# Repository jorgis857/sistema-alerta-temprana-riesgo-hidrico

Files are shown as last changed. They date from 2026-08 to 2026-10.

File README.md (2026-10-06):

# 💧 WREWS — Water Risk Early Warning System

**Internet de las Cosas — Challenge #1 — 2026-2**
Facultad de Ingeniería, Universidad de La Sabana




[]()

> **WREWS (Water Risk Early Warning System)** es un prototipo IoT de bajo costo que monitorea la disponibilidad de agua y genera alertas tempranas ante condiciones asociadas a un posible riesgo de desabastecimiento. El sistema combina el nivel actual, las condiciones ambientales favorables a la evaporación y la velocidad de descenso del nivel para generar un **índice de riesgo hídrico** y comunicar localmente los estados 🟢 NORMAL, 🟡 PRECAUCIÓN y 🔴 CRÍTICO.

---

## 🎯 El reto

El Challenge #1 plantea el desarrollo de una solución IoT orientada al monitoreo de la disponibilidad de agua y a la generación de alertas tempranas locales.

WREWS aborda el problema mediante tres dimensiones principales:

```text
DISPONIBILIDAD ACTUAL
Nivel del reservorio
        50 %
          │
          │
CONDICIONES AMBIENTALES
VPD + irradiancia estimada
        30 %
          │
          ▼
    RIESGO HÍDRICO
          ▲
          │
TENDENCIA DEL NIVEL
Tasa de descenso
        20 %
```

El procesamiento se realiza localmente en un **ESP32**, por lo que la generación de la alerta no depende de Wi-Fi, Internet, servicios en la nube ni otra infraestructura de comunicaciones.

📄 **Documentación técnica completa:** [`/wiki`](wiki/00-Home.md)

---

## ✅ Estado actual

WREWS fue desarrollado mediante dos etapas complementarias:

### 1. Simulación en Wokwi

Se desarrolló inicialmente una simulación para:

- validar la arquitectura;
- probar la adquisición de sensores;
- comprobar el bus I²C;
- desarrollar y probar *custom chips*;
- verificar los cálculos;
- reproducir diferentes escenarios;
- validar los estados NORMAL, PRECAUCIÓN y CRÍTICO;
- depurar el firmware antes de integrar el hardware.

### 2. Prototipo físico

Posteriormente se construyó un **prototipo físico funcional** que integra:

- ESP32;
- sensor ultrasónico OKY3261/HC-SR04;
- BME280;
- mini panel fotovoltaico;
- INA219;
- LCD 16×2 I²C;
- LEDs verde, amarillo y rojo;
- buzzer;
- maqueta con plataforma móvil para representar diferentes niveles de agua.

Las pruebas físicas permitieron verificar la cadena completa:

```text
SENSADO
   ↓
ADQUISICIÓN
   ↓
PROCESAMIENTO
   ↓
FUSIÓN DE INFORMACIÓN
   ↓
CLASIFICACIÓN
   ↓
ALERTA LOCAL
```

---

## 🧭 Navegación rápida de la Wiki

| # | Sección | Contenido |
|---|---|---|
| 0 | [Home](wiki/00-Home.md) | Índice general de la Wiki |
| 1 | [Resumen, motivación y justificación](wiki/01-Resumen-Motivacion.md) | Contexto, problemática, objetivo y justificación |
| 2 | [Solución propuesta](wiki/02-Solucion-Propuesta.md) | Arquitectura, variables, procesamiento y lógica de riesgo |
| 3 | [Desarrollo modular](wiki/03-Desarrollo-Modular.md) | Modelo matemático, UML, hardware y estrategia de implementación |
| 4 | [Modelo de negocio](wiki/04-Modelo-de-Negocio.md) | Business Model Canvas |
| 5 | [Configuración experimental y resultados](wiki/05-Configuracion-Experimental-Resultados.md) | Simulación, pruebas físicas y análisis de resultados |
| 6 | [Autoevaluación del protocolo de pruebas](wiki/06-Autoevaluacion-Pruebas.md) | Cobertura, fortalezas y limitaciones |
| 7 | [Conclusiones, retos y trabajo futuro](wiki/07-Conclusiones-Trabajo-Futuro.md) | Resultados finales, retos y oportunidades de mejora |
| 8 | [Uso de Inteligencia Artificial](wiki/08-Uso-de-IA.md) | Declaración de uso de IA |
| 9 | [Equipo de trabajo](wiki/09-Equipo-Roles.md) | Roles, contribuciones, acta y autoevaluación |
| 10 | [Executive Summary (English)](wiki/10-English-Executive-Summary.md) | Resumen ejecutivo en inglés |
| 11 | [Conectividad IoT](wiki/11-Conectividad-IoT.md) | Actividad de refuerzo #2.3: red de nodos con MQTT |
| 12 | [Mejoras respecto al Challenge #1](wiki/12-Mejoras-Challenge-1.md) | Retroalimentación del Challenge #1 y cómo se atendió |

---

## 🗂️ Estructura del repositorio

```text
sistema-alerta-temprana-riesgo-hidrico/
├── README.md
├── LICENSE
│
├── wiki/
│   ├── 00-Home.md
│   ├── 01-Resumen-Motivacion.md
│   ├── 02-Solucion-Propuesta.md
│   ├── 03-Desarrollo-Modular.md
│   ├── 04-Modelo-de-Negocio.md
│   ├── 05-Configuracion-Experimental-Resultados.md
│   ├── 06-Autoevaluacion-Pruebas.md
│   ├── 07-Conclusiones-Trabajo-Futuro.md
│   ├── 08-Uso-de-IA.md
│   ├── 09-Equipo-Roles.md
│   ├── 10-English-Executive-Summary.md
│   ├── 11-Conectividad-IoT.md
│   └── 12-Mejoras-Challenge-1.md
│
├── firmware/
│   ├── wrews/                  (abrir wrews.ino en Arduino IDE)
│   │   ├── wrews.ino
│   │   ├── tablero.h
│   │   └── secrets.example.h   (copiar como secrets.h)
│   └── libraries.txt
│
├── hardware/
│   ├── wokwi/
│   │   ├── diagram.json
│   │   ├── wokwi-project-link.txt
│   │   └── chips/
│   └── schematics/
│       └── diagrama_circuito_wokwi.png
│
└── video/
    └── GUION_VIDEO.md
```

---

## ⚙️ Simulación en Wokwi

La simulación utilizada durante el desarrollo está disponible en:

**https://wokwi.com/projects/472250559337371649**

Para probarla:

1. Abrir el proyecto en Wokwi.
2. Iniciar la simulación.
3. Modificar los controles asociados a temperatura, humedad, presión e irradiancia.
4. Modificar la distancia del sensor ultrasónico.
5. Observar las variables calculadas y los cambios de estado.

La simulación permite reproducir:

```text
🟢 NORMAL
     ↓
🟡 PRECAUCIÓN
     ↓
🔴 CRÍTICO
```

> **Nota:** la simulación original utiliza una pantalla OLED SSD1306 como interfaz virtual. Durante la implementación física esta fue sustituida por una **LCD 16×2 I²C**. El firmware y los archivos almacenados en `hardware/wokwi/` corresponden a esta etapa de simulación y se conservan como evidencia del proceso de desarrollo.

---

## 🧩 Componentes del prototipo físico

| Función | Sensor / Actuador | Interfaz |
|---|---|---|
| Temperatura, humedad y presión | BME280 | I²C |
| Estimación de irradiancia | Mini panel fotovoltaico + INA219 | I²C |
| Nivel | OKY3261 / HC-SR04 | GPIO TRIG/ECHO |
| Visualización local | LCD 16×2 I²C | I²C |
| Alerta visual | LED verde / amarillo / rojo | GPIO digital |
| Alerta sonora | Buzzer | GPIO digital |
| Procesamiento | ESP32 | — |

---

## 🧠 Procesamiento del riesgo

WREWS utiliza tres componentes principales.

### 💧 Disponibilidad de agua

El sensor ultrasónico mide la distancia hasta la superficie que representa el agua.

Esta distancia se convierte en un porcentaje de nivel mediante la calibración correspondiente a las dimensiones de la maqueta.

### 🌡️ Condiciones ambientales

El BME280 obtiene temperatura y humedad relativa para calcular el **Vapor Pressure Deficit (VPD)**.

La señal obtenida mediante el panel fotovoltaico y el INA219 permite realizar una estimación experimental de irradiancia.

Ambas variables se combinan para obtener un **índice de condiciones favorables a la evaporación**.

### 📉 Tendencia

WREWS analiza diferentes mediciones del nivel a lo largo del tiempo para estimar su **tasa de descenso**.

Esto permite detectar reducciones aceleradas incluso antes de que el nivel alcance una condición extremadamente baja.

---

## 🚦 Sistema de alertas

La información procesada se transforma en tres estados:

| Estado | Indicador | Interpretación |
|---|---|---|
| 🟢 **NORMAL** | LED verde | Condiciones dentro del rango esperado |
| 🟡 **PRECAUCIÓN** | LED amarillo | Existen condiciones que requieren atención |
| 🔴 **CRÍTICO** | LED rojo + buzzer | Se detectó una condición de riesgo elevado |

La **LCD 16×2 I²C** proporciona información local adicional sobre el sistema.

---

## 🧪 Validación

La validación se realizó en dos niveles:

```text
WOKWI
Simulación controlada
      ↓
PROTOTIPO FÍSICO
Sensores + ESP32 + actuadores
      ↓
VALIDACIÓN FUNCIONAL
```

En el prototipo físico se verificó:

- respuesta del sensor ultrasónico;
- adquisición del BME280;
- adquisición del INA219 y panel;
- cálculo y procesamiento local;
- tasa de descenso;
- estados NORMAL, PRECAUCIÓN y CRÍTICO;
- LCD;
- LEDs;
- buzzer.

Para representar el nivel del agua se utilizó una **plataforma móvil** cuya altura puede modificarse frente al sensor ultrasónico.

Esto permite realizar pruebas repetibles sin exponer la electrónica directamente al agua.

Los resultados y el análisis completo se encuentran en:

[`wiki/05-Configuracion-Experimental-Resultados.md`](wiki/05-Configuracion-Experimental-Resultados.md)

---

## 🎥 Video de demostración

El video final presenta:

- problemática abordada;
- funcionamiento de WREWS;
- sensores utilizados;
- procesamiento de las variables;
- VPD e índice evaporativo;
- tasa de descenso;
- clasificación del riesgo;
- demostración del prototipo físico;
- estados NORMAL, PRECAUCIÓN y CRÍTICO.

El guion utilizado durante la producción se encuentra en:

[`video/GUION_VIDEO.md`](video/GUION_VIDEO.md)

> 🎬 **Video final de demostración:** [WREWS — Water Risk Early Warning System](https://youtu.be/zUS3DWeHSsw)

---

## 👥 Equipo 2

| Integrante | Rol principal |
|---|---|
| **Mateo Ramírez Cabrera** | Hardware e integración de sensores |
| **Antonio Benítez Rueda** | Firmware y lógica de fusión de datos |
| **Jorge Andrés Rodríguez Huertas** | Documentación, pruebas y gestión del proyecto |

El detalle de las contribuciones, compromisos y autoevaluación se encuentra en:

[`wiki/09-Equipo-Roles.md`](wiki/09-Equipo-Roles.md)

---

## 🤖 Uso de Inteligencia Artificial

El proyecto utilizó herramientas de Inteligencia Artificial como apoyo durante diferentes etapas del desarrollo.

La declaración y descripción correspondiente se mantiene documentada en:

[`wiki/08-Uso-de-IA.md`](wiki/08-Uso-de-IA.md)

---

## 📌 Resultado

WREWS evolucionó desde una arquitectura simulada hasta un **prototipo físico funcional**.

El sistema integra:

```text
NIVEL
   +
CONDICIONES AMBIENTALES
   +
TASA DE DESCENSO
   ↓
ÍNDICE DE RIESGO HÍDRICO
   ↓
NORMAL / PRECAUCIÓN / CRÍTICO
   ↓
LCD + LEDs + Buzzer
```

El prototipo demuestra la posibilidad de generar una **alerta temprana local de riesgo hídrico** mediante sensores de bajo costo y procesamiento embebido en un ESP32.

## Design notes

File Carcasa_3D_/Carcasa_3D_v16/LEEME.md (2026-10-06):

# WREWS – Carcasa v16 (el USB-C ya no choca con la cápsula del BME)

La caja mide **136 × 110 × 73 mm**. Reemplaza la v15. Son las 6 piezas completas, listas para imprimir.

## Qué cambió respecto a la v15

El problema real no era el agujerito de los cables del BME: era **el hueco del USB-C con su capucha**, que al ensanchar la caja en la v14 quedó justo encima de la cápsula del BME (la capucha del USB ocupaba X 1–25 mm y la cápsula X −15 a 15 mm, a la misma altura). Por eso en los intentos anteriores seguía viéndose igual.

- El hueco del USB-C se movió a **X = 42 mm** (hacia el lado de la proto, lejos del centro). Ahora queda **15 mm separado de la cápsula del BME** y 3 mm antes del tornillo de la esquina. Sigue estando dentro del ancho de la mini proto.
- Se devolvieron las **5 persianas** de la cápsula y el agujero de cables del BME a su posición original (nunca fueron el problema).
- Las 6 piezas se regeneraron y todas dan watertight = True.

**Importante al armar:** pongan el ESP32 en la mini proto de forma que su puerto USB-C quede mirando a la pared de atrás y corrido hacia el lado de afuera (a unos 9 mm del centro de la proto, hacia la pared lateral). Si al armar queda en otro lado, me dicen la medida y lo ajusto, o se usa un cable USB-C un poco más largo por dentro.

## Por qué la caja quedó más ancha que en versiones anteriores (heredado de la v14)

El portapilas real mide **61,5 × 52,6 × 15 mm** — mucho más grande en huella (y más plano) que lo que se había asumido antes (31 × 58 × 30 mm). Con el ancho anterior (104 mm interior) el portapilas real y la mini proto (85 × 56 mm) no cabían lado a lado sin chocar. Por eso el ancho interior pasó de 104 a 130 mm.

Además, a todo se le dejó margen de sobra, no medidas justas:

| Elemento | Medida real | Medida usada en el modelo | Margen |
|---|---|---|---|
| Mini proto (ESP32+INA219) | 85 × 56 mm | 89 × 59 mm | +3–4 mm |
| Portapilas 4×AA | 61,5 × 52,6 mm | 64,5 × 55,6 mm (lado corto hacia el ancho de la caja) | +3 mm |
| Interruptor (balancín 3 pines, foto) | ~19×13 mm el cuerpo | hueco 22×16 mm, marco 29×23 mm, capucha con 9 mm de fondo | holgado a propósito |
| Ventana LCD | pantalla 71,1×24,3 mm | 76,1×29,3 mm | +5 mm |
| Ranura USB-C | conector real | 16×10 mm | +1,5 mm más que en v13 |
| Bolsillo del panel solar | grosor real + 3 mm | grosor real + 4 mm | +1 mm más |

Entre la bandeja de la proto y la del portapilas quedan 11 mm de separación, y 2,2 mm de margen a cada pared lateral (más el borde estructural de 1,2 mm).

## Piezas (en `stl/`)

| # | Archivo | Tiempo aprox. | Cómo imprimir |
|---|---|---|---|
| 1 | `1_prueba_ajuste_tubo.stl` | 40 min | Plano. Es opcional |
| 2 | `2_acople_tubo.stl` | 2–3 h | Brida sobre la cama |
| 3 | `3_tapa.stl` | 2–3 h | Techo hacia arriba, con soportes solo desde la cama (debajo del labio) |
| 4 | `4_caja.stl` | 8–10 h | Piso sobre la cama, sin soportes |
| 5 | `5_piso_intermedio.stl` | 1 h | Plano sobre la cama, sin soportes |
| 6 | `6_techo_bme.stl` | 15 min | El tapón hueco va sobre la cama; el techito queda arriba |

Material PETG o ASA, capa de 0,2 mm, 3–4 perímetros y relleno de 30–40 %. La `4_caja` es la que más tarda — arráncenla primero.

## Lo que sigue pendiente (sin tocar, para más adelante)

- Posición real del USB-C (`USB_OFF_X`, estimado en -20).
- Grosor real del panel solar (`PANEL_ALTO`, estimado en 7 mm).
- El layout donde el ESP32 queda "metido en la del BME" — sigue anotado para reorganizar en otra versión, no era urgente para imprimir mañana.

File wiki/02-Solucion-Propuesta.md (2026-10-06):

[⬅ Volver al índice](00-Home.md)

# 2. Solución propuesta

## 2.1 Descripción general
**WREWS (Water Risk Early Warning System)** es un prototipo funcional de bajo costo diseñado para monitorear la disponibilidad de agua y generar alertas tempranas de riesgo hídrico.

El sistema utiliza un **ESP32** como unidad central de adquisición y procesamiento. A partir de diferentes sensores se analizan tres dimensiones principales:

1. **Disponibilidad actual de agua**, mediante el nivel.
2. **Condiciones ambientales favorables a la evaporación**, mediante temperatura, humedad e irradiancia estimada.
3. **Tendencia del nivel**, mediante su tasa de descenso.

Estas variables son procesadas y fusionadas localmente para clasificar la situación en tres estados:

- 🟢 **NORMAL**
- 🟡 **PRECAUCIÓN**
- 🔴 **CRÍTICO**

La notificación se realiza de forma completamente local mediante una **pantalla LCD 16×2 I²C**, LEDs de estado y un buzzer.

En el Challenge #2 se añade un **tablero de control web** alojado en un servidor embebido en el ESP32 y publicado en la WLAN de la zona. Desde un navegador (PC o celular conectado a esa WLAN, con usuario y contraseña) las autoridades ven el valor actual y el histórico reciente de las variables, reciben avisos de cada cambio de estado, silencian la alarma física y calibran el equipo.

---

## 2.2 Restricciones y decisiones de diseño

| Tipo | Restricción / necesidad | Decisión de diseño |
|---|---|---|
| **Técnica** | El sistema debe monitorear la disponibilidad de agua | Se utiliza un sensor ultrasónico OKY3261/HC-SR04 para medir la distancia hasta la superficie y convertirla en porcentaje de nivel |
| **Técnica** | Deben considerarse variables ambientales | Se utiliza un BME280 para adquirir temperatura, humedad relativa y presión atmosférica |
| **Técnica** | Se requiere considerar la radiación solar | Se utiliza un mini panel fotovoltaico junto con un INA219 para obtener una señal relacionada con la irradiancia recibida |
| **Técnica** | Se requiere notificación *in situ* con alarma física y visualización en tiempo real | Toda la actuación es local mediante LCD 16×2 I²C, LEDs verde/amarillo/rojo y buzzer, y no depende de la red |
| **Técnica (Ch. #2)** | Tablero de control en un servidor web embebido, conectado a la WLAN de la zona; no MQTT | Servidor HTTP en el ESP32 (librería `WebServer`), en modo estación (STA) sobre la WLAN; sin broker ni nube |
| **Técnica (Ch. #2)** | La medición debe ejecutarse en una ISR o en un hilo distinto al principal | La medición corre en una tarea de FreeRTOS en el núcleo 0; las alarmas en otra tarea del núcleo 1; el servidor y el LCD en `loop()`. Dos mutex protegen el estado compartido y el bus I²C |
| **Seguridad (Ch. #2)** | Acceso al tablero restringido a dispositivos autorizados y conectados a la WLAN de la zona | Doble condición: el cliente debe estar en la misma subred del equipo y tener una sesión iniciada con usuario y contraseña (cookie con token aleatorio de 128 bits, bloqueo tras 5 intentos fallidos) |
| **Operativa (Ch. #2)** | El equipo debe instalarse cerrado, como producto terminado | Carcasa impresa en 3D (PETG), sensor de nivel dentro de un tubo de PVC sanitario de 3", alimentación por pilas con interruptor, y calibración desde el tablero sin abrir la caja |
| **Robustez (Ch. #2)** | Pérdida y reconexión de la WLAN | La alarma física no depende de la red; el ESP32 se reconecta solo y admite hasta dos redes configuradas |
| **Regulatoria · eléctrica** | Seguridad eléctrica cerca del agua: RETIE [32] | Todo funciona en muy baja tensión (pilas, 5 V y 3.3 V) dentro de la carcasa; no hay 110 V cerca del agua |
| **Regulatoria · agua** | Infraestructura de acueducto: Resolución 0330 de 2017, RAS [33] | El equipo es complementario: mide sin contacto dentro de un tubo de PVC y no interviene la tubería ni la operación del acueducto |
| **Regulatoria · intemperie** | Grado de protección de la envolvente: IEC 60529 [34] | Carcasa cerrada con el BME280 bajo un techo ventilado; el grado IP no se ensayó y se declara como trabajo futuro |
| **Regulatoria · gestión del riesgo** | Ley 1523 de 2012 [35]: a quién se reporta | El tablero está pensado para la junta de acueducto y la unidad municipal de gestión del riesgo; el registro de eventos con su hora sirve de soporte para el reporte |
| **Regulatoria · datos** | Ley 1581 de 2012 [36] | El tablero no maneja datos personales; el acceso es restringido y cada inicio de sesión y cada clave incorrecta quedan registrados con la dirección del dispositivo |
| **Regulatoria · espectro** | Uso de radiofrecuencia [37] | Wi-Fi en la banda de 2.4 GHz, de uso libre en Colombia |
| **Temporal** | Entrega en dos semanas a partir del Challenge #1 | Se reutilizaron ESP32, sensores, LCD y la lógica de fusión; lo nuevo se construyó por etapas (modelo, hilos, Wi-Fi y tablero, calibración) probando cada una en el hardware |
| **Temporal · muestreo** | Fenómenos lentos, pero la tasa necesita muchas muestras | Medición cada 1 s (mediana de 5 ecos para el nivel); evaporación sobre una ventana móvil; historial del tablero con un punto cada 2 s durante 10 min |
| **Técnica** | Los sensores utilizan diferentes interfaces | BME280, INA219 y LCD utilizan el bus I²C; el sensor ultrasónico utiliza GPIO digital para TRIG y ECHO |
| **Técnica** | El sistema debe detectar cambios en el comportamiento del nivel | Se comparan mediciones sucesivas para estimar la tasa de descenso |
| **Técnica** | Una condición crítica no debe quedar oculta por un promedio | Además del índice ponderado se utilizan reglas de seguridad independientes |
| **Económica** | El prototipo debe ser de bajo costo | Se seleccionaron componentes comerciales, accesibles y reutilizables |
| **Operativa** | El usuario debe interpretar fácilmente el estado | Se utilizan tres estados y una codificación semafórica: verde, amarillo y rojo |
| **Operativa** | El sistema debe funcionar sin infraestructura externa | Todo el procesamiento se ejecuta localmente en el ESP32 |

---

## 2.3 Variables monitoreadas

WREWS adquiere o calcula las siguientes variables:

| Variable | Fuente | Uso |
|---|---|---|
| Distancia | Sensor ultrasónico | Medición base para determinar el nivel |
| Nivel (%) | Calculado | Representa la disponibilidad actual de agua |
| Temperatura | BME280 | Cálculo de condiciones ambientales |
| Humedad relativa | BME280 | Cálculo de condiciones ambientales |
| Presión atmosférica | BME280 | Variable ambiental de contexto |
| Señal del panel | Panel + INA219 | Estimación de irradiancia |
| Irradiancia estimada | Calculada | Evaluación de condiciones favorables a la evaporación |
| VPD | Calculado | Representa la demanda evaporativa de la atmósfera |
| Radiación neta y evaporación potencial (mm/día) | Calculadas (Priestley-Taylor + FAO-56) | Estimación física de la evaporación de agua libre a escala diaria |
| Índice evaporativo | Calculado | Resume las condiciones favorables a la evaporación |
| Tasa de descenso | Calculada | Representa la tendencia del nivel |
| Índice de riesgo | Calculado | Fusión de disponibilidad, ambiente y tendencia |
| Estado | Calculado | NORMAL, PRECAUCIÓN o CRÍTICO |

---

## 2.4 Arquitectura general

```mermaid
flowchart LR

    ULTRA[Sensor ultrasónico<br/>Nivel]
    BME[BME280<br/>Temperatura<br/>Humedad<br/>Presión]
    PANEL[Mini panel<br/>fotovoltaico]
    INA[INA219]

    MCU[ESP32<br/>Adquisición y procesamiento]

    LCD[LCD 16x2<br/>I2C]
    LEDV[LED verde]
    LEDA[LED amarillo]
    LEDR[LED rojo]
    BUZZ[Buzzer]

    PANEL --> INA

    ULTRA --> MCU
    BME --> MCU
    INA --> MCU

    MCU --> LCD
    MCU --> LEDV
    MCU --> LEDA
    MCU --> LEDR
    MCU --> BUZZ

    WLAN[WLAN de la zona<br/>hotspot en la demo]
    NAV[Navegador<br/>PC / celular autorizado]
    MCU <-->|Wi-Fi STA · HTTP| WLAN
    WLAN <--> NAV
```

El **ESP32** constituye el núcleo del sistema.

Los sensores proporcionan la información de entrada, el microcontrolador realiza los cálculos y finalmente controla los dispositivos de salida según el riesgo detectado.

En el Challenge #2 el mismo ESP32 sirve el tablero de control: se une como estación a la WLAN de la zona y responde a los navegadores autorizados dentro de ella. No hay broker, nube ni servidor externo.

### Diagrama de bloques del software (Challenge #2)

```mermaid
flowchart LR
    subgraph N0["Núcleo 0"]
        TM[tareaMedicion · 1 s<br/>sensores → modelo → estado<br/>historial y eventos]
    end
    subgraph N1["Núcleo 1"]
        TA[tareaAlarmas · 10 ms<br/>LEDs y buzzer]
        LP[loop<br/>servidor web · Wi-Fi · LCD]
    end
    EST[(Estado compartido<br/>mtx_estado)]
    I2C[(Bus I²C<br/>mtx_i2c)]
    NVS[(Flash NVS<br/>calibración)]

    TM --> EST
    TA --> EST
    LP --> EST
    TM --> I2C
    LP --> I2C
    LP --> NVS
```

---

## 2.5 Flujo de procesamiento

El funcionamiento general de WREWS sigue el siguiente flujo:

```mermaid
flowchart TD

    A[Inicio] --> B[Lectura de sensores]

    B --> C[Calcular porcentaje de nivel]
    B --> D[Obtener temperatura y humedad]
    B --> E[Obtener señal del panel]

    D --> F[Calcular VPD]
    E --> G[Estimar irradiancia]

    F --> H[Calcular índice evaporativo]
    G --> H

    C --> I[Actualizar historial del nivel]
    I --> J[Calcular tasa de descenso]

    C --> K[Calcular déficit de nivel]

    K --> L[Fusión de información]
    H --> L
    J --> L

    L --> M[Calcular índice de riesgo]

    M --> N{Clasificación}

    N -->|Crítico| O[LCD + LED rojo + Buzzer]
    N -->|Precaución| P[LCD + LED amarillo]
    N -->|Normal| Q[LCD + LED verde]

    O --> B
    P --> B
    Q --> B
```

---

## 2.6 Medición del nivel

El sensor ultrasónico se instala sobre el punto de almacenamiento y mide la distancia hasta la superficie.

La relación general es:

```text
Distancia pequeña
        ↓
Nivel alto

Distancia grande
        ↓
Nivel bajo
```

El porcentaje de nivel se obtiene mediante una calibración basada en las posiciones correspondientes a lleno y vacío.

De forma general:

```text
Nivel (%) =
100 × (Distancia_vacío - Distancia_medida)
      -------------------------------------
      (Distancia_vacío - Distancia_lleno)
```

El resultado se limita al rango:

```text
0 % ≤ Nivel ≤ 100 %
```

En la implementación física, los valores de calibración corresponden a las dimensiones reales de la maqueta.

Para las pruebas se utiliza una **plataforma móvil que representa la superficie del agua**. Al modificar su altura se pueden reproducir diferentes niveles de manera controlada.

---

## 2.7 Condiciones ambientales

### Temperatura, humedad y presión

El BME280 proporciona:

```text
Temperatura
Humedad relativa
Presión atmosférica
```

La temperatura y la humedad se utilizan para calcular el **VPD — Vapor Pressure Deficit**.

Conceptualmente:

```text
TEMPERATURA ──┐
              ├──→ VPD
HUMEDAD ──────┘
```

Un VPD mayor representa condiciones atmosféricas más favorables para la pérdida de agua por evaporación.

La presión atmosférica se conserva como una variable ambiental complementaria.

Debido a que su variación esperada en un punto fijo es relativamente pequeña, no participa directamente como disparador principal del riesgo.

---

## 2.8 Estimación de irradiancia

La radiación solar se representa mediante un mini panel fotovoltaico.

La cadena de adquisición es:

```text
RADIACIÓN
    ↓
PANEL FOTOVOLTAICO
    ↓
INA219
    ↓
SEÑAL ELÉCTRICA
    ↓
IRRADIANCIA ESTIMADA
```

Cuando aumenta la energía luminosa recibida por el panel, cambia su respuesta eléctrica.

El INA219 permite adquirir esta señal para que el ESP32 pueda utilizarla dentro del procesamiento.

La irradiancia obtenida debe interpretarse como una **estimación experimental**.

El panel fotovoltaico no sustituye un piranómetro calibrado, por lo que una medición metrológica precisa en W/m² requeriría una calibración frente a un instrumento de referencia.

---

## 2.9 Índice de condiciones favorables a la evaporación

En el Challenge #2, WREWS estima la **evaporación potencial diaria** con el modelo de **Priestley-Taylor**, usando las ecuaciones de **FAO-56** para la radiación neta y los parámetros psicrométricos, y la combina con el VPD.

Conceptualmente:

```text
PANEL → INA219 → IRRADIANCIA ──┐
                               ├──→ RADIACIÓN NETA ──┐
TEMPERATURA · HUMEDAD ─────────┘                     ├──→ EVAPORACIÓN (mm/día) ── 70 %──┐
TEMPERATURA · PRESIÓN ───────────→ Δ/(Δ+γ) ──────────┘                                  ├──→ ÍNDICE EVAPORATIVO
TEMPERATURA · HUMEDAD ───────────→ VPD de la ventana ────────────────────────── 30 % ───┘
```

El resultado representa qué tan favorables son las condiciones ambientales para la evaporación. El detalle del modelo, sus constantes y sus referencias están en la [Sección 3.2.3](03-Desarrollo-Modular.md).

Es importante señalar que:

> **El índice evaporativo no representa el porcentaje de agua que se ha evaporado.**

Representa un indicador relativo de las **condiciones ambientales que favorecen la evaporación**.

---

## 2.10 Tasa de descenso

Una medición instantánea del nivel no permite determinar cómo está evolucionando el almacenamiento.

Por esta razón, WREWS compara mediciones tomadas en diferentes momentos.

Conceptualmente:

```text
Nivel anterior - Nivel actual
-----------------------------
       Tiempo transcurrido
```

Esto permite estimar la **tasa de descenso del nivel**.

Por ejemplo:

```text
Reservorio A
Nivel = 50 %
Tasa ≈ 0
→ relativamente estable

Reservorio B
Nivel = 50 %
Tasa de descenso alta
→ disponibilidad disminuyendo rápidamente
```

De esta forma, la tendencia aporta información adicional a la disponibilidad instantánea.

---

## 2.11 Fusión de información

La lógica principal combina tres componentes:

```text
                 WREWS

       DISPONIBILIDAD ACTUAL
          Déficit de nivel
                54 %
                 │
                 │
CONDICIONES ─────┼───── TENDENCIA
AMBIENTALES      │      DEL NIVEL
Priestley-Taylor │      Tasa de
+ VPD            │      descenso
30 %             │      16 %
                 │
                 ▼
          ÍNDICE DE RIESGO
                 │
                 ▼
       NORMAL / PRECAUCIÓN /
              CRÍTICO
```

La ponderación utilizada es:

```text
Riesgo =
0.54 × Déficit de nivel
+
0.30 × Índice evaporativo
+
0.16 × Tendencia
```

La mayor ponderación corresponde al nivel porque la **disponibilidad actual de agua constituye la variable principal del problema**. En el Challenge #2 los pesos pasaron de 50/30/20 a 54/30/16: son el vector de pesos del método AHP de Saaty aplicado a la comparación por pares de las tres señales (ver [Sección 3.2.5](03-Desarrollo-Modular.md)).

Las condiciones ambientales permiten anticipar escenarios favorables a una mayor pérdida de agua y la tendencia permite identificar reducciones aceleradas.

---

## 2.12 Reglas de seguridad

El índice ponderado no constituye el único mecanismo de decisión.

WREWS incorpora reglas de seguridad para condiciones individuales extremas.

Esto evita una situación como:

```text
Nivel extremadamente bajo
+
Ambiente favorable
+
Tasa estable
```

en la que el promedio matemático pudiera reducir artificialmente la percepción del riesgo.

Por tanto:

```text
ÍNDICE PONDERADO
       +
REGLAS DE SEGURIDAD
       ↓
ESTADO FINAL
```

Excepción introducida en el Challenge #2: la **evaporación por sí sola lleva como máximo a PRECAUCIÓN**. La evaporación es un forzante, no la disponibilidad de agua: un mediodía seco y soleado con el embalse lleno no es una emergencia. Su severidad completa se sigue mostrando en el tablero y entra al riesgo combinado con su peso, de modo que con el nivel bajo el riesgo sí lleva a CRÍTICO.

---

## 2.13 Estados del sistema

### 🟢 NORMAL

Representa condiciones en las que la disponibilidad de agua y los demás indicadores no muestran un riesgo significativo.

Respuesta local:

```text
LCD → NORMAL
LED verde → activo
Buzzer → apagado
```

### 🟡 PRECAUCIÓN

Indica que una o varias variables han alcanzado condiciones que justifican atención.

Respuesta local:

```text
LCD → PRECAUCIÓN
LED amarillo → activo
Buzzer → pitido grave corto (1000 Hz, 150 ms cada 4 s)
```

### 🔴 CRÍTICO

Representa una situación de riesgo elevado o una condición individual considerada crítica.

Respuesta local:

```text
LCD → CRÍTICO
LED rojo → parpadea
Buzzer → alarma sonora (2000 Hz, 250 ms cada 1.2 s)
```

### ⚙️ FALLO

Condición del equipo, no nivel de riesgo: sin eco del sensor de nivel o sin BME280 en el bus I²C.

```text
LEDs → los tres parpadean a la vez
Buzzer → tono muy grave (600 Hz, 120 ms cada 3 s)
```

En todos los estados el buzzer puede **silenciarse durante 15 minutos desde el tablero de control**; los LEDs siguen mostrando el estado, y si este empeora el silencio se cancela solo.

---

## 2.14 Visualización local

La implementación física utiliza una **LCD 16×2 I²C**.

Debido al espacio disponible en la pantalla, la información se organiza para presentar las variables más relevantes y el estado del sistema sin interferir con el procesamiento interno.

En el firmware v7 la LCD rota cada 2.5 s entre siete páginas:

| Página | Línea 1 | Línea 2 |
|---|---|---|
| 1 | Nivel (%) o `SIN ECO` | Estado (y `MUTE` si el buzzer está silenciado) |
| 2 | Temperatura | Humedad relativa |
| 3 | Presión | VPD |
| 4 | Irradiancia (`NOCHE` si < 5 W/m²) | Índice evaporativo, o `calc NN%` mientras se llena la ventana |
| 5 | Severidad de cada variable y riesgo | Tasa de descenso |
| 6 | Evaporación potencial (mm/día) | Radiación neta y modo (DEMO/CAMPO) |
| 7 | Estado del Wi-Fi | **IP del tablero** (o `buscando red...`) |

Los LEDs permiten interpretar rápidamente la clasificación:

```text
🟢 Verde     → NORMAL
🟡 Amarillo  → PRECAUCIÓN
🔴 Rojo      → CRÍTICO
```

El buzzer añade una señal sonora cuando se identifica una condición crítica, con un tono distinto para precaución, crítico y fallo.

---

## 2.15 Alerta local independiente de la red

Una característica importante del diseño es que la generación de la alerta no depende de infraestructura externa. En el Challenge #2 el tablero web se suma como un segundo canal de notificación, pero la cadena de abajo sigue completa aunque la WLAN no esté disponible.

Todo ocurre dentro del dispositivo:

```text
SENSORES
   ↓
ESP32
   ↓
PROCESAMIENTO
   ↓
DECISIÓN
   ↓
LCD + LEDs + BUZZER
```

No se requiere:

- Wi-Fi;
- Bluetooth;
- LoRa;
- GSM;
- servicios en la nube;
- conexión a Internet.

Esto permite que el sistema continúe generando alertas locales incluso en un lugar sin conectividad.

---

## 2.16 Simulación e implementación física

El desarrollo se realizó en dos etapas.

### Simulación

Wokwi permitió:

- diseñar la arquitectura;
- probar sensores;
- desarrollar *custom chips*;
- comprobar el bus I²C;
- probar escenarios controlados;
- verificar la lógica de riesgo;
- depurar el firmware.

La simulación original utiliza algunos componentes virtuales diferentes a los finalmente disponibles para el montaje físico.

### Implementación física

Posteriormente se integraron los componentes reales y se ajustó el sistema a las características de la maqueta.

La pantalla utilizada en el prototipo físico final es una **LCD 16×2 I²C**, seleccionada por disponibilidad y porque permite cumplir el requisito de visualización local.

Por tanto, la simulación debe entenderse como una etapa de desarrollo y validación previa, mientras que la implementación física representa la versión final presentada en el Challenge.

### Producto terminado (Challenge #2)

En el Challenge #2 el prototipo deja la maqueta de laboratorio y se integra como un equipo listo para instalar:

- **Carcasa** impresa en 3D en PETG, diseñada en CadQuery, con el ESP32, el INA219, el LCD, los LEDs y el buzzer dentro, el BME280 bajo un techo con rejillas de ventilación y el panel solar en la parte superior.
- **Sensor de nivel** dentro de un tubo de PVC sanitario de 3" (40 a 50 cm, con entradas de agua en la parte inferior), que se instala en el punto de almacenamiento.
- **Alimentación** por un portapilas 4×AA con interruptor.
- **Tablero de control** en la WLAN de la zona, que permite calibrar el equipo con la carcasa cerrada.

El detalle está en las [Secciones 3.14 a 3.19](03-Desarrollo-Modular.md).

---

## 2.17 Locación y contexto físico (Challenge #2)

| Aspecto | Definición del equipo |
|---|---|
| **Punto crítico** | Lago del campus de la Universidad de La Sabana (Chía, Sabana Centro) como sitio de instalación y pruebas; como alternativa, el tanque de un acueducto veredal de Chía o Cajicá. El nodo se instala en la orilla, anclado a un poste o baranda, y mide dentro de un tubo de PVC que llega por debajo del nivel mínimo |
| **Ambiente** | Intemperie a ≈ 2560 m s. n. m.: lluvia, radiación UV alta, heladas en temporada seca y humedad alta en la noche |
| **Alimentación** | Pilas en el prototipo; en campo, red de 5 V con respaldo o panel solar con baterías. El servidor web obliga a tener el Wi-Fi siempre encendido |
| **Conectividad** | WLAN de la junta o la alcaldía, con el punto de acceso a ≤ 30 m y línea de vista; objetivo de señal ≥ −70 dBm en el punto de instalación |
| **Acceso y mantenimiento** | Montaje con tornillería antivandalismo; mantenimiento mensual (limpiar el sensor, revisar la alimentación); calibración desde el tablero, sin tocar el agua |
| **Rango de variables** | Nivel: 0–2 m en un tanque típico (en el prototipo, el recorrido del tubo); temperatura ≈ 0–25 °C; HR 40–95 %; presión ≈ 750 hPa; radiación hasta ≈ 1100–1200 W/m² al mediodía |
| **Seguridad del sitio** | Solo muy baja tensión dentro de la caja; nada de 110 V cerca del agua |

⟨completar: fotos del sitio, medidas y RSSI medido en el punto de instalación, si se hizo la visita⟩

---

[⬅ Anterior: Resumen y motivación](01-Resumen-Motivacion.md) · [⬆ Índice](00-Home.md) · [Siguiente: Desarrollo modular ➡](03-Desarrollo-Modular.md)

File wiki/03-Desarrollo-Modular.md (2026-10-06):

[⬅ Volver al índice](00-Home.md)

# 3. Desarrollo teórico modular

## 3.1 Criterios de diseño establecidos

| Criterio | Decisión de diseño | Justificación |
|---|---|---|
| **Independencia de red** | Toda la lógica de decisión corre en el ESP32; no hay llamadas a servicios externos. El tablero del Challenge #2 solo publica lo que el equipo ya decidió | La alarma *in situ* funciona aunque la WLAN no esté disponible |
| **Medición en hilo propio (Ch. #2)** | Tres hilos de FreeRTOS: medición (núcleo 0), alarmas (núcleo 1) y servidor/LCD (`loop()`, núcleo 1) | Cumple la restricción del enunciado y evita que un navegador lento o una caída de la red congelen la alarma física |
| **Acceso restringido (Ch. #2)** | Misma subred que el equipo + sesión con usuario y contraseña | Solo dispositivos autorizados y conectados a la WLAN de la zona ven los datos o actúan sobre la alarma |
| **Producto cerrado (Ch. #2)** | Calibración desde el tablero, guardada en la flash del ESP32 | La carcasa no se abre para ajustar el equipo en el sitio |
| **Trazabilidad de los parámetros (Ch. #2)** | Cada constante del modelo cita su fuente en el código y en la Sección 7.5; las que no tienen fuente se declaran como supuesto | Responde a la observación del Challenge #1 de que los valores no se anclaban a literatura ni normativa |
| **Modularidad funcional** | El firmware se organiza por responsabilidades: lectura de sensores, cálculo de nivel, VPD, índice evaporativo, tasa de descenso, riesgo y actuación | Facilita mantenimiento, depuración y reemplazo de sensores |
| **Múltiples señales, una decisión** | El riesgo hídrico depende de la fusión de nivel, condiciones evaporativas y tendencia | Responde a la necesidad de combinar múltiples señales para una alerta más completa |
| **Ninguna variable crítica queda oculta por el promedio** | Se incorporan reglas de seguridad independientes al promedio ponderado | Reduce el riesgo de falsos negativos ante condiciones individuales extremas |
| **Calibración simple** | El nivel se ajusta mediante parámetros de distancia correspondientes a lleno y vacío (en el Challenge #2, desde el tablero) | Permite adaptar el sistema a distintas geometrías |
| **Simulación antes del montaje físico** | Se validó inicialmente la arquitectura y lógica en Wokwi | Redujo errores antes de integrar sensores reales |
| **Validación física posterior** | El sistema fue implementado sobre una maqueta funcional | Permite verificar sensores, actuadores y comportamiento real del sistema |
| **Legibilidad para usuarios no técnicos** | LCD 16×2 I²C + LEDs semafóricos + buzzer | Facilita la interpretación local del estado |
| **Enfoque en la problemática hídrica** | El nivel y su tendencia son las variables principales; la presión se mantiene como contexto | Mantiene la lógica alineada con el riesgo de disponibilidad y desabastecimiento |

---

## 3.2 Modelo matemático de fusión de datos

### 3.2.1 Nivel del reservorio

El porcentaje de nivel se calcula a partir de la distancia medida por el sensor ultrasónico:

```text
Nivel (%) =
100 × (D_vacío - D_medida)
      ----------------------
      (D_vacío - D_lleno)
```

El resultado se limita al rango:

```text
0 % ≤ Nivel ≤ 100 %
```

En la implementación física, `D_lleno` y `D_vacío` corresponden a la calibración real de la maqueta.

---

### 3.2.2 Déficit de presión de vapor — VPD

La temperatura y la humedad relativa permiten calcular el déficit de presión de vapor.

De forma general:

```text
e_s = presión de vapor de saturación
e_a = presión de vapor actual

VPD = e_s - e_a
```

El VPD representa la capacidad del aire para aceptar vapor de agua adicional.

Un valor mayor indica condiciones más favorables para la evaporación.

---

### 3.2.3 Índice evaporativo

> **Challenge #2:** el índice del Challenge #1 (50 % irradiancia normalizada + 50 % VPD normalizado, con un factor de altitud sobre la irradiancia) se reemplazó por la **evaporación potencial diaria de Priestley-Taylor** [5] con los parámetros de **FAO-56** [6]. El reparto 50/50 no tenía respaldo en la literatura; el modelo nuevo sí, y además usa la presión medida en vez de un factor fijo.

#### Ecuación de Priestley-Taylor

```text
λ·ET = α · Δ/(Δ+γ) · (Rn − G)        [MJ/m²·día]
ET   = λ·ET / λ                       [mm/día]
```

Es una simplificación de Penman que conserva el término radiativo y reemplaza el aerodinámico por el coeficiente α. Rosenberry et al. [7] compararon 15 métodos en un lago de montaña contra el balance de energía, y Priestley-Taylor quedó entre los tres mejores (error medio de 0.19 mm/día).

#### Cálculo, en el orden del firmware

Con los promedios de una ventana móvil de mediciones (T media, Tmax, Tmin, HR media, P media):

| # | Magnitud | Fórmula | Fuente |
|---|---|---|---|
| 1 | Presión de vapor de saturación | `es(T) = 0.6108 · exp(17.27·T / (T + 237.3))` | [6] ec. 11 |
| 2 | Pendiente de la curva de saturación | `Δ = 4098 · es(T) / (T + 237.3)²` | [6] ec. 13 |
| 3 | Constante psicrométrica, con la **presión medida** | `γ = 0.000665 · P` | [6] ec. 8 |
| 4 | Presión de vapor real | `ea = (HR/100) · (es(Tmax) + es(Tmin)) / 2` | [6] ec. 19 |
| 5 | Radiación de cielo despejado | `Rso = (0.75 + 2·10⁻⁵ · z) · Ra` | [6] ec. 37 |
| 6 | Relación de nubosidad | `r = Rs / Rso`, limitada entre 0.3 y 1.0 | [6] (máximo); el mínimo es supuesto propio |
| 7 | Onda corta neta | `Rns = (1 − a) · Rs` | [6] ec. 38 |
| 8 | Onda larga neta | `Rnl = σ · (Tmax,K⁴ + Tmin,K⁴)/2 · (0.34 − 0.14·√ea) · (1.35·r − 0.35)` | [6] ec. 39 |
| 9 | Radiación neta | `Rn = max(Rns − Rnl, 0)` | [6] |
| 10 | Flujo de calor almacenado | `G = 0` a escala diaria | [6] ec. 42 (supuesto en agua) |
| 11 | Evaporación potencial | `ET = α · Δ/(Δ+γ) · Rn / λ` | [5] |

#### Constantes

| Constante | Valor | Fuente / estado |
|---|---|---|
| α (Priestley-Taylor) | 1.26 | [5], superficie de agua libre sin advección. Seleshi [14] encontró 1.11 en trópico de altura; se deja configurable y su calibración en el embalse es trabajo futuro |
| Albedo del agua `a` | 0.06 | [8]; Xiao et al. [12] midieron 0.041 y 0.079 |
| Calor latente λ | 2.45 MJ/kg | [6] |
| σ (Stefan-Boltzmann) | 4.903·10⁻⁹ MJ·K⁻⁴·m⁻²·día⁻¹ | [6] ec. 39 |
| Altitud `z` | 2560 m | Sitio; **solo** se usa en Rso. γ usa la presión medida |
| Radiación extraterrestre Ra | 36 MJ/m²·día, fija | [6] ec. 21 y anexo 2. A ~5° N varía entre ~33.5 y ~37.5: error < 3 % en ET sin necesidad de fecha ni reloj |
| Constante del panel K | 10 (W/m²)/mA | Etiqueta del panel (100 mA a 1000 W/m²) [9], [10]. **Pendiente de calibrar con sol** |

#### Ventana móvil y modos

El modelo es válido a escala diaria [5], [6]. La energía de radiación y los promedios de T, HR y P se acumulan en una ventana móvil de 24 *buckets* (no se guarda cada muestra: 24 h a 1 Hz serían 86 400 muestras).

- **Modo campo:** ventana de 24 h reales. `Rs_día = energía acumulada · 86 400 / tiempo cubierto`.
- **Modo demo:** ventana corta (120 s por defecto) cuyo promedio de luz se toma como **el mediodía de un día con esa nubosidad**, mediante el índice de claridad: `Rs_día = min(G / G_pico, 1) · Rso`, con `G_pico = π · Rso / (2 · 12 h) ≈ 1049 W/m²`, la irradiancia de un mediodía despejado del sitio para un día senoidal de 12 h. Una primera versión extrapolaba la ventana corta a 24 h iguales; con sol real (831 W/m²) eso daba 72 MJ/m² "por día", 2.5 veces el máximo físico, y el índice se saturaba siempre (ver [Sección 7.2](07-Conclusiones-Trabajo-Futuro.md)).
- Mientras la ventana esté cubierta en menos del 50 %, el estado de la evaporación es `CALCULANDO`: el índice vale 0 y no dispara reglas. En el tablero se muestra como "estimación en curso".

#### Índice evaporativo (0–100)

```text
Índice_evap = 70 · min(ET / ET_REF, 1) + 30 · min(VPD / VPD_REF, 1)
ET_REF  = 7.5 mm/día   (ET de un día despejado del sitio con este mismo modelo)
VPD_REF = 2.0 kPa      (supuesto: tarde seca del percentil alto de la Sabana)
VPD     = (es(Tmax) + es(Tmin))/2 − ea   ([6] ec. 12), promedio de la ventana
```

- **ET_REF** sale del propio modelo con Rs = Rso, T = 16 °C (22/8 °C), HR = 65 %, P = 75 kPa: Rn = 20.8 MJ/m²·día, Δ/(Δ+γ) = 0.699, ET = 7.48 mm/día. Así el 100 % de la parte de Priestley-Taylor es la demanda evaporativa máxima posible del sitio, sin traer un número de afuera.
- **El componente de VPD (30 %)** se justifica con Jansen et al. [11]: en un embalse grande, a escala de horas y días la evaporación sigue sobre todo al gradiente de vapor y al viento, que Priestley-Taylor no ve. El peso de 0.3 es el reparto aerodinámico de Penman γ/(Δ+γ) [6] a 16 °C y 75 kPa. Como α ya incluye en promedio la parte aerodinámica, el VPD se lee como señal de variación diaria, no como una evaporación que se suma. WREWS no mide viento ni temperatura del agua, así que el VPD del aire es una aproximación.
- **El VPD es el de la ventana**, no el de un instante: así queda en la misma escala de tiempo que ET y no salta con cada pico de mediodía.

Este índice:

> **No representa el porcentaje de agua que se evapora.**

Representa, en una escala relativa, qué tan favorables son las condiciones ambientales para la evaporación, normalizado contra un día despejado del propio sitio.

**Papel de la presión atmosférica.** La presión no se emplea como indicador de riesgo: en una estación fija de la región tropical su variación es de apenas un par de hectopascales sobre una presión de fondo de ~745 hPa, y no cambia cuando hay desabastecimiento. Sí participa como **parámetro del modelo de evaporación**, a través de la constante psicrométrica `γ = 0.665·10⁻³·P`, que determina el reparto entre el término radiativo y el aerodinámico. En el Challenge #2 entra directamente en Δ/(Δ+γ) con la presión medida por el BME280; el factor de altitud fijo del Challenge #1 se eliminó.

**Papel de la humedad en Priestley-Taylor.** La humedad solo entra al término radiativo a través de `ea` en Rnl, con un efecto pequeño (≈ 3 % al bajar la HR de 75 a 50 %). Sin luz, Rn = 0 y la parte de Priestley-Taylor vale 0 por mucho calor que haga: en esas condiciones el índice solo puede llegar a 30 por el componente de VPD. Esto se observó en las pruebas con secador sin luz sobre el panel (Sección 5.7).

**Supuestos declarados:**

1. Superficie de agua libre sin efecto oasis [5]: se cumple en un embalse; el banco de pruebas no lo cumple y solo valida la cadena de cálculo, no el valor absoluto de evaporación.
2. G ≈ 0 a escala diaria: [6] lo justifica para suelo; para agua profunda, Jansen et al. [11] y Xiao et al. [12] advierten que el calor almacenado no es despreciable.
3. Rnl de FAO-56, calibrada para tierra, aplicada sobre agua: aproximación habitual.
4. Ra fijo: error < 3 % en ET.
5. Modo demo: supone una forma de día típica de 12 h; no reemplaza la ventana de 24 h de campo.

---

### 3.2.4 Tasa e índice de descenso

La primera versión del sistema estimaba la tendencia restando dos mediciones consecutivas de nivel. Ese método resultó inviable ya que con el ruido del sensor la tasa superaba por mucho el umbral crítico, incluso con la plataforma quieta.

La versión final estima la pendiente por **regresión lineal por mínimos cuadrados** sobre una ventana de las últimas 20 mediciones. La regresión promedia el ruido de todas las muestras en vez de depender de dos.

```text
Tasa (pp/min) = − pendiente de la recta ajustada a los pares (tiempo, nivel) de la ventana
```

Cuando el nivel sube, la pendiente se trunca a cero: una recarga no constituye riesgo hídrico.

**Banda muerta.** Por debajo de un umbral derivado del ruido medido del propio sensor, la pendiente se fuerza a cero. Ese umbral se calcula automáticamente en cada arranque (ver Sección 5).

**Discontinuidades.** Un reservorio real no cambia de nivel de forma instantánea. Variaciones superiores a 8 puntos porcentuales entre mediciones consecutivas se interpretan como recarga del reservorio —o, en la maqueta, como reposicionamiento manual de la plataforma— y descartan el historial acumulado de tendencia. Sin este tratamiento, la regresión ajustada sobre un escalón produce una pendiente que crece por sí sola mientras el escalón avanza por la ventana.

**Precauciones numéricas.** El eje temporal se expresa relativo a la muestra más antigua de la ventana. Usando el tiempo absoluto del sistema en punto flotante, los términos del denominador de la regresión se aproximan entre sí y su diferencia se pierde por cancelación a los pocos minutos de encendido.

### 3.2.5 Riesgo hídrico

El riesgo general se calcula mediante:

```text
Riesgo =
0.54 × Déficit de nivel
+
0.30 × Índice evaporativo
+
0.16 × Índice de descenso
```

La mayor ponderación corresponde al nivel porque representa directamente la disponibilidad actual de agua.

**Origen de los pesos (Challenge #2).** No existe una fuente que fije "el nivel pesa 50 %"; lo que sí existe es un método citado para derivar pesos de criterio experto: el **Proceso Analítico Jerárquico (AHP)** de Saaty [18], el más usado para construir índices compuestos de sequía [19]. Se compararon las tres señales por pares en la escala 1–9 de Saaty:

| | Nivel | Evaporación | Tasa |
|---|---|---|---|
| **Nivel** | 1 | 2 | 3 |
| **Evaporación** | 1/2 | 1 | 2 |
| **Tasa** | 1/3 | 1/2 | 1 |

El nivel es "levemente más importante" que la evaporación y "moderadamente más importante" que la tasa, y la evaporación es levemente más importante que la tasa: el nivel es la variable de estado, la evaporación es el forzante dominante en El Niño y la tasa es la señal más ruidosa de las tres. El vector de pesos resultante es **54 / 30 / 16 %**, con una razón de consistencia **CR = 0.008** (< 0.10, el límite de Saaty). Los 50/30/20 del Challenge #1 eran prácticamente ese mismo vector redondeado.

---

### 3.2.6 Reglas de clasificación de estado

La lógica de clasificación incorpora el índice ponderado y reglas de seguridad.

| Estado | Condición general |
|---|---|
| 🔴 **CRÍTICO** | Riesgo elevado o alguna variable individual alcanza un umbral crítico (excepto la evaporación, ver abajo) |
| 🟡 **PRECAUCIÓN** | Riesgo intermedio o alguna variable supera su umbral de advertencia |
| 🟢 **NORMAL** | Ninguna condición de precaución o crítica está activa |

La implementación utiliza umbrales definidos en el firmware para:

- nivel;
- índice evaporativo;
- tasa de descenso;
- riesgo combinado.

Estos valores corresponden a parámetros iniciales de diseño y pueden recalibrarse para una instalación real.

**La evaporación sola lleva como máximo a PRECAUCIÓN (Challenge #2).** El estado es la peor severidad de nivel, tasa y riesgo, y de la evaporación limitada a precaución. La evaporación es un forzante, no la disponibilidad de agua: con el embalse lleno, un mediodía seco y soleado no es una emergencia, y dejar que disparara CRÍTICO producía falsos positivos (se observó en las pruebas al sol, Sección 5.7). Su severidad completa se sigue reportando en el tablero ("demanda extrema") y entra al riesgo con su peso del 30 %: con el nivel bajo, el riesgo combinado sí lleva a CRÍTICO.

---

### 3.2.7 Umbrales aplicados

| Variable | PRECAUCIÓN | CRÍTICO | Origen del valor |
|---|---|---|---|
| Nivel del reservorio | ≤ 50 % | ≤ 15 % | Fases de los Planes Especiales de Sequía de España [20], [21] (prealerta 0.50, emergencia 0.15); caso Chingaza 2024, racionamiento con el sistema en 16.5 % [22] |
| Índice evaporativo | ≥ 60 | ≥ 85 (solo como severidad; el estado llega como máximo a PRECAUCIÓN) | **Supuesto.** El 100 % tiene base física (ET_REF); 60 y 85 deben cerrarse con los percentiles 80 y 95 de una estación del IDEAM, método del US Drought Monitor [23] |
| Tasa de descenso | ≥ 33 pp/min | ≥ 68 pp/min | **Calibración experimental** (Sección 5); editables desde el tablero |
| Riesgo ponderado | ≥ 36.2 | ≥ 69.2 | Derivados de los de nivel, al estilo de los indicadores por fases como el CDI europeo [24] |

**Derivación de los umbrales de riesgo.** No hay literatura para el número exacto porque el índice es propio; se derivan de los umbrales de nivel, que sí están citados:

```text
PRECAUCIÓN = 0.54·(100 − 50) + 0.30·20 + 0.16·20 = 36.2   (nivel en precaución, el resto en reposo)
CRÍTICO    = 0.54·(100 − 15) + 0.30·60 + 0.16·33 = 69.2   (nivel en crítico, el resto en su precaución)
```

**Mapeo de las fases de los PES a los estados de WREWS:**

| Fase en los PES | Índice | Estado WREWS |
|---|---|---|
| Normalidad | > 0.50 | NORMAL |
| Prealerta y alerta | 0.50 a 0.15 | PRECAUCIÓN |
| Emergencia | ≤ 0.15 | CRÍTICO |

Limitación declarada: el índice de los PES es el volumen normalizado contra la historia del propio embalse, no exactamente el porcentaje de llenado; para el prototipo es una aproximación razonable.

Referencias de normalización del índice evaporativo: ET_REF = 7.5 mm/día y VPD_REF = 2.0 kPa (Sección 3.2.3). La de VPD se fijó a partir del clima local: a 24 °C la presión de vapor de saturación es 2.98 kPa, de modo que 2.0 kPa representa una tarde seca del percentil alto de la región. Una referencia mayor dejaría el índice permanentemente por debajo de sus umbrales.

Los umbrales de tasa corresponden al banco de pruebas, donde la plataforma se desplaza manualmente en segundos. No deben interpretarse como límites hidrológicos de un reservorio real: en campo, con una escala temporal de horas, los valores equivalentes serían del orden de 0.03 y 0.08 pp/min.

### 3.2.8 Escalera de estados y confirmación temporal

Las transiciones se producen de un nivel a la vez, incluso cuando las condiciones instantáneas corresponden a un estado dos escalones por encima. Así PRECAUCIÓN es siempre observable, lo que permite anticipar la escalada y deja el historial completo en el registro.

La confirmación es **asimétrica**: dos ciclos consecutivos para escalar y tres para desescalar. Los costos de los dos errores posibles no son equivalentes: alertar tarde en un evento de desabastecimiento puede impedir la respuesta, mientras que sostener una alerta unos segundos de más no tiene costo operativo. La banda muerta, los retardos de confirmación y la escalera de estados son prácticas de gestión de alarmas industriales: la norma ANSI/ISA-18.2 exige que el sistema soporte banda muerta y retardos [16], y EEMUA 191 da valores de referencia para la banda muerta [17].

El estado **FALLO** no participa de la escalera. No es un nivel de riesgo sino una condición del equipo —ausencia de eco del ultrasónico, o del BME280 en el bus I²C— y se entra y se sale de forma directa. Su señalización, los tres LEDs parpadeando a la vez, no se confunde con ningún estado operativo: un sistema de alerta que enmudece cuando pierde un sensor es la peor falla posible.

## 3.3 Diagramas UML

Diagramas actualizados al firmware v7 del Challenge #2 (`firmware/wrews/wrews.ino` y `tablero.h`).

### 3.3.1 Diagrama de estados

```mermaid
stateDiagram-v2
    [*] --> NORMAL

    NORMAL --> PRECAUCION: condición de advertencia\n(confirmada 2 ciclos)
    PRECAUCION --> CRITICO: condición crítica\n(confirmada 2 ciclos)
    CRITICO --> PRECAUCION: riesgo disminuye\n(confirmado 3 ciclos)
    PRECAUCION --> NORMAL: condiciones mejoran\n(confirmado 3 ciclos)

    NORMAL --> FALLO: sin eco o sin BME280
    PRECAUCION --> FALLO: sin eco o sin BME280
    CRITICO --> FALLO: sin eco o sin BME280
    FALLO --> NORMAL: sensores de vuelta

    state NORMAL {
        [*] --> LED_Verde
        LED_Verde: LED verde fijo
        LED_Verde: buzzer apagado
    }

    state PRECAUCION {
        [*] --> LED_Amarillo
        LED_Amarillo: LED amarillo fijo
        LED_Amarillo: buzzer 1000 Hz, 150 ms cada 4 s
    }

    state CRITICO {
        [*] --> LED_Rojo
        LED_Rojo: LED rojo parpadeando
        LED_Rojo: buzzer 2000 Hz, 250 ms cada 1.2 s
    }

    state FALLO {
        [*] --> Tres_LEDs
        Tres_LEDs: los tres LEDs parpadeando
        Tres_LEDs: buzzer 600 Hz, 120 ms cada 3 s
    }
```

Se sube y se baja de a un peldaño: de NORMAL nunca se salta directo a CRÍTICO, así PRECAUCIÓN siempre es observable. En cualquier estado, el silencio desde el tablero calla solo el buzzer durante 15 min; si el estado empeora, el silencio se cancela.

---

### 3.3.2 Diagrama de secuencia — ciclo de medición

```mermaid
sequenceDiagram
    participant TM as tareaMedicion (núcleo 0)
    participant ULTRA as HC-SR04
    participant I2C as Bus I²C (mtx_i2c)
    participant EST as Estado compartido (mtx_estado)
    participant TA as tareaAlarmas (núcleo 1)
    participant ACT as LEDs / Buzzer

    loop cada 1 s (vTaskDelayUntil)
        TM->>ULTRA: 5 pulsos TRIG, mediana de 5 ecos
        ULTRA-->>TM: distancia
        TM->>I2C: tomar bus
        TM->>I2C: leer BME280 (T, HR, P) e INA219 (corriente)
        TM->>I2C: liberar bus
        TM->>EST: tomar candado
        TM->>TM: nivel, tasa (regresión), ventana de evaporación,<br/>Priestley-Taylor, índice, riesgo
        TM->>TM: clasificar y aplicar escalera de estados
        TM->>TM: registrar eventos e historial
        TM->>EST: liberar candado
    end

    loop cada 10 ms
        TA->>EST: copiar estado y silencio
        TA->>ACT: patrón de LEDs y buzzer
    end
```

La lectura del HC-SR04 (~100 ms) se hace **antes** de tomar el candado del estado, para no frenar las alarmas. El orden de los candados es fijo (nunca se toma el del bus teniendo el del estado), lo que evita bloqueos mutuos.

---

### 3.3.3 Diagrama de secuencia — tablero de control

```mermaid
sequenceDiagram
    actor U as Autoridad (navegador en la WLAN)
    participant SRV as loop(): servidor web
    participant EST as Estado compartido
    participant TA as tareaAlarmas

    U->>SRV: GET /
    SRV-->>U: redirige a /login (sin sesión)
    U->>SRV: POST /login (usuario, clave)
    SRV->>SRV: ¿misma subred? ¿credenciales? (bloqueo tras 5 fallos)
    SRV-->>U: cookie con token de sesión, redirige a /
    U->>SRV: GET / (tablero)

    loop cada 2 s
        U->>SRV: GET /api/actual
        SRV->>EST: copiar estado (candado)
        SRV-->>U: JSON con valores actuales
        opt cambió el último evento
            U->>SRV: GET /api/eventos?desde=N
            SRV-->>U: eventos nuevos → aviso en pantalla
        end
    end

    loop cada 5 s
        U->>SRV: GET /api/historial
        SRV-->>U: últimos 10 min (1 punto cada 2 s)
    end

    U->>SRV: POST /api/silenciar
    SRV->>EST: silenciarAlarma() (candado)
    TA->>EST: lee "silenciado"
    TA->>TA: buzzer apagado 15 min, LEDs igual
    SRV-->>U: confirmación + evento
```

---

### 3.3.4 Diagrama de componentes de software

```mermaid
classDiagram

    class TareaMedicion {
        +tomarMuestra()
        +actualizarModelo()
        +guardarHistorial()
    }

    class SensorUltrasonico {
        +leerDistancia()
    }

    class SensoresI2C {
        +leerBME280()
        +leerINA219()
    }

    class ModuloNivel {
        +distanciaANivel()
        +calcularTasa()
    }

    class ModuloEvaporacion {
        +ventanaAcumular()
        +evaluarVentana()
        +priestleyTaylor()
        +indiceEvaporativo()
    }

    class ModuloRiesgo {
        +severidad()
        +calcularObjetivo()
        +aplicarEstado()
    }

    class TareaAlarmas {
        +actualizarAlarmas()
        +buzzer()
        +silenciarAlarma()
    }

    class LoopPrincipal {
        +servidor.handleClient()
        +vigilarWiFi()
        +mostrarPagina()
    }

    class ServidorWeb {
        +procesarLogin()
        +apiActual()
        +apiHistorial()
        +apiEventos()
        +apiSilenciar()
        +apiParametros()
    }

    class Parametros {
        +cargarParametros()
        +guardarParametros()
        +validarParametros()
    }

    class RegistroEventos {
        +registrarEvento()
    }

    TareaMedicion --> SensorUltrasonico
    TareaMedicion --> SensoresI2C
    TareaMedicion --> ModuloNivel
    TareaMedicion --> ModuloEvaporacion
    TareaMedicion --> ModuloRiesgo
    ModuloRiesgo --> RegistroEventos
    TareaAlarmas --> ModuloRiesgo : lee estado
    LoopPrincipal --> ServidorWeb
    ServidorWeb --> RegistroEventos
    ServidorWeb --> TareaAlarmas : silenciar
    ServidorWeb --> Parametros
    Parametros --> ModuloNivel : distancias, tasa
    Parametros --> ModuloEvaporacion : K, ET_REF, modo
```

---

## 3.4 Arquitectura física

La versión final presentada utiliza los siguientes componentes:

```text
                 ┌───────────────┐
                 │     ESP32     │
                 │ procesamiento │
                 └───────┬───────┘
                         │
       ┌─────────────────┼──────────────────┐
       │                 │                  │
       ▼                 ▼                  ▼
Sensor ultrasónico     BME280        Panel + INA219
Nivel                  T / HR / P     Irradiancia aprox.

                         │
                         ▼
                 Procesamiento local
                         │
                         ▼
              NORMAL / PRECAUCIÓN /
                     CRÍTICO
                         │
          ┌──────────────┼──────────────┬──────────────────┐
          ▼              ▼              ▼                  ▼
      LCD 16×2         LEDs           Buzzer     Wi-Fi → tablero web
                                                 (WLAN de la zona)
```

La simulación original de Wokwi se conserva en la carpeta `/hardware/wokwi` como evidencia del proceso de diseño previo. Corresponde al firmware del Challenge #1; el firmware v7 (tareas de FreeRTOS, Wi-Fi y servidor web) se validó directamente sobre el hardware.

El hardware físico final utiliza una LCD 16×2 I²C como interfaz local.

---

## 3.5 Comunicación I²C

El sistema aprovecha el bus I²C para conectar varios módulos al ESP32.

Los dispositivos principales son:

| Dispositivo | Interfaz | Dirección |
|---|---|---|
| BME280 | I²C | `0x76` |
| INA219 | I²C | `0x40` |
| LCD 16×2 | I²C | `0x27` |

El firmware escanea el bus al arrancar e identifica cada dispositivo por su dirección; si falta el BME280 el equipo pasa a FALLO, y si falta el INA219 la irradiancia se toma como 0.

El bus utiliza las líneas:

```text
SDA
SCL
```

compartidas entre los dispositivos.

Cada módulo utiliza una dirección propia, permitiendo que el ESP32 pueda comunicarse con varios periféricos sobre el mismo bus.

En el Challenge #2 el bus lo usan dos hilos distintos: la tarea de medición (BME280 e INA219) y `loop()` (LCD). Un mutex (`mtx_i2c`) garantiza que nunca haya dos transacciones I²C a la vez.

---

## 3.6 Sensor ultrasónico

El sensor ultrasónico utiliza dos señales digitales:

```text
TRIG
ECHO
```

El ESP32 genera un pulso sobre `TRIG`.

El sensor responde mediante `ECHO`, cuya duración permite estimar la distancia.

De manera simplificada:

```text
ESP32
  │
  ├── TRIG ──→ Sensor
  │
  └── ECHO ←── Sensor
```

Esta distancia se transforma posteriormente en porcentaje de nivel.

---

## 3.7 Pantalla LCD 16×2 I²C

La interfaz física final utiliza una pantalla LCD 16×2 con adaptador I²C.

La pantalla cumple dos funciones principales:

1. presentar información relevante del sistema;
2. mostrar al usuario el estado de riesgo.

Debido a la limitación de 16 caracteres por 2 filas, la interfaz prioriza la información esencial y organiza las variables en diferentes vistas o ciclos de actualización.

El procesamiento de todas las variables continúa realizándose internamente en el ESP32 aunque no todas se muestren simultáneamente.

En el firmware v7 la LCD rota entre siete páginas cada 2.5 s; la séptima muestra el estado del Wi-Fi y la **IP del tablero**, que es como el usuario sabe a qué dirección entrar (el detalle de las páginas está en la [Sección 2.14](02-Solucion-Propuesta.md)).

---

## 3.8 LEDs y buzzer

Los LEDs utilizan una codificación semafórica:

```text
Verde     → NORMAL
Amarillo  → PRECAUCIÓN
Rojo      → CRÍTICO
```

El buzzer actúa como alarma sonora adicional en el estado crítico.

En el firmware v7 cada estado tiene su patrón, para que se reconozca sin mirar el equipo:

| Estado | LEDs | Buzzer |
|---|---|---|
| NORMAL | Verde fijo | Apagado |
| PRECAUCIÓN | Amarillo fijo | 1000 Hz, 150 ms cada 4 s |
| CRÍTICO | Rojo parpadeando (200 ms cada 400 ms) | 2000 Hz, 250 ms cada 1.2 s |
| FALLO | Los tres parpadeando | 600 Hz, 120 ms cada 3 s |

Los LEDs son de ánodo común (se encienden en `LOW`). El buzzer es **pasivo** y se maneja con PWM (LEDC). La frecuencia del PWM se cambia solo cuando cambia el estado, y cada pitido se enciende y apaga con el ciclo útil (50 % / 0 %), que no reinicia la onda. El tono de crítico es de **2000 Hz** porque un barrido de 500 a 4000 Hz mostró que el buzzer del prototipo no suena desde 2500 Hz (Sección 5.7).

El silencio desde el tablero apaga **solo el buzzer** durante 15 minutos: los LEDs siguen mostrando el estado, porque la condición de riesgo no desaparece porque alguien la reconozca.

Esto proporciona dos mecanismos de notificación:

```text
VISUAL
LCD + LEDs

SONORO
Buzzer
```

---

## 3.9 Diseño de la maqueta

Para validar el sensor de nivel se construyó una maqueta con una plataforma móvil.

La plataforma representa la superficie del agua.

```text
Plataforma arriba
       ↓
Distancia pequeña
       ↓
Nivel alto

Plataforma abajo
       ↓
Distancia grande
       ↓
Nivel bajo
```

Esta solución permitió:

- controlar la distancia;
- repetir escenarios;
- observar las transiciones de estado;
- evitar contacto entre agua y electrónica;
- acelerar las pruebas durante la validación.

---

## 3.10 Estrategia de simulación

Antes del montaje físico se desarrolló una versión funcional en Wokwi.

La simulación permitió:

- validar el sensor ultrasónico;
- comprobar el bus I²C;
- simular temperatura, humedad y presión;
- simular el panel y el INA219;
- probar la lógica matemática;
- modificar las variables mediante controles;
- verificar NORMAL, PRECAUCIÓN y CRÍTICO.

En Wokwi se utilizaron *custom chips* para representar componentes que requerían comportamiento configurable.

La simulación original utiliza una pantalla OLED como componente virtual. Posteriormente, durante la implementación física, esta interfaz fue reemplazada por una **LCD 16×2 I²C** disponible para el equipo.

Este cambio no modifica la arquitectura lógica del sistema: ambos dispositivos cumplen la función de visualización local mediante I²C.

---

## 3.11 Estrategia de implementación física

Después de validar la lógica en simulación se integró el prototipo físico.

El proceso general fue:

```text
Prueba del ESP32
      ↓
Sensor ultrasónico
      ↓
LCD + buzzer
      ↓
BME280
      ↓
Panel + INA219
      ↓
LEDs
      ↓
Integración completa
      ↓
Calibración
      ↓
Pruebas de estados
```

Durante esta etapa se realizaron ajustes propios del hardware real, especialmente relacionados con:

- calibración de distancia;
- estabilidad de las lecturas;
- bus I²C;
- actuación de LEDs;
- comportamiento del buzzer;
- organización de la información en la LCD.

---

## 3.12 Estándares y buenas prácticas de ingeniería

| Estándar / práctica | Aplicación |
|---|---|
| **I²C** | Comunicación entre ESP32, BME280, INA219 y LCD |
| **UML** | Modelado de estados, secuencia y componentes |
| **Codificación semafórica** | Verde = normal, amarillo = precaución, rojo = crítico |
| **Diseño modular** | Separación de lectura, procesamiento, fusión y actuación |
| **Validación progresiva** | Simulación antes de implementación física |
| **Reglas de seguridad** | Condiciones críticas individuales pueden prevalecer sobre el promedio |
| **Procesamiento local** | El sistema no depende de servicios externos para generar alertas |
| **Calibración** | Los parámetros del nivel se ajustan a la geometría del sistema evaluado |
| **FAO-56 (Allen et al.) [6] y Priestley-Taylor [5]** | Ecuaciones de radiación neta, Δ, γ y evaporación potencial (Ch. #2) |
| **AHP de Saaty [18]** | Derivación de los pesos 54/30/16 del riesgo (Ch. #2) |
| **Planes Especiales de Sequía — Orden TEC/1399/2018 [20], [21]** | Umbrales de nivel de 50 % y 15 % (Ch. #2) |
| **ANSI/ISA-18.2 [16] y EEMUA 191 [17]** | Gestión de alarmas: banda muerta, retardos de confirmación, escalera de estados y silencio sin ocultar el estado |
| **IEEE 802.11 (Wi-Fi) [29]** | Enlace del ESP32 a la WLAN de la zona, banda de 2.4 GHz (Ch. #2) |
| **HTTP/1.1 — RFC 9110 [30]** | Servidor web embebido y API JSON del tablero (Ch. #2) |
| **FreeRTOS / ESP-IDF [31]** | Tareas por núcleo, `vTaskDelayUntil` y mutex para el estado compartido (Ch. #2) |

---

## 3.13 Flujo completo del sistema

```text
SENSOR ULTRASÓNICO
        ↓
      NIVEL
        │
        │
        ├───────────────────────────┐
        │                           │
        ▼                           │
 DÉFICIT DE NIVEL                   │
      54 %                          │
                                    │
BME280                              │
T + HR + P                          │
  ↓                                 │
 VPD · Δ/(Δ+γ) ─┐                   │
                ├→ PRIESTLEY-TAYLOR │
PANEL           │  + VPD            │
  ↓             │  ÍNDICE EVAP. ───┤
INA219          │       30 %        │
  ↓             │                   │
IRRADIANCIA ────┘                   │
                                    ├→ RIESGO
NIVEL EN EL TIEMPO                  │
        ↓                           │
TASA DE DESCENSO ───────────────────┘
       16 %
        ↓
REGLAS DE SEGURIDAD
        ↓
NORMAL / PRECAUCIÓN / CRÍTICO
        ↓
LCD + LEDs + Buzzer   ·   tablero web en la WLAN
```

---

## 3.14 Concurrencia: medición en un hilo propio (Challenge #2)

El enunciado exige que la medición se ejecute desde una ISR o desde un hilo distinto al principal. El firmware v7 usa tres hilos de FreeRTOS [31]:

| Hilo | Núcleo | Prioridad | Periodo | Responsabilidad |
|---|---|---|---|---|
| `tareaMedicion` | 0 | 2 | 1 s (`vTaskDelayUntil`) | Lee los sensores, actualiza el modelo (nivel, tasa, evaporación, riesgo), decide el estado y guarda historial y eventos |
| `tareaAlarmas` | 1 | 2 | 10 ms | LEDs y buzzer |
| `loop()` | 1 | 1 | continuo | Servidor web, vigilancia del Wi-Fi y páginas del LCD |

- **Por qué las alarmas van aparte del servidor:** un navegador lento o una caída de la WLAN pueden bloquear `loop()` unos segundos; con las alarmas en su propia tarea, la alarma física no se congela nunca.
- **Estado compartido:** un mutex (`mtx_estado`) protege todas las variables que leen o escriben varios hilos. Las lecturas lentas de los sensores se hacen **fuera** del candado, que solo se toma para actualizar el estado.
- **Bus I²C:** un segundo mutex (`mtx_i2c`) evita que la tarea de medición y el LCD usen el bus al mismo tiempo.
- **Orden fijo de los candados** (nunca se toma el del bus teniendo el del estado), para que no haya bloqueos mutuos.
- **No se usan ISR:** las lecturas I²C y los cálculos en coma flotante no deben ejecutarse dentro de una rutina de interrupción.

---

## 3.15 Conectividad: Wi-Fi en modo estación (Challenge #2)

- **Modo estación (STA):** el ESP32 se une a la WLAN que las autoridades ofrecen en la zona; en la demostración, el hotspot de un celular. No crea su propia red, de acuerdo con el enunciado.
- **Banda de 2.4 GHz** (IEEE 802.11 b/g/n [29]); el ESP32 no se conecta a redes de 5 GHz.
- **Una o dos redes configuradas.** El equipo se une a la que encuentre con mejor señal y, si una se cae, prueba con la otra. Los nombres y las claves van en `secrets.h`, que no se sube al repositorio (plantilla en `secrets.example.h`).
- **Sin ahorro de energía en el radio** (`WiFi.setSleep(false)`): con el ahorro activo, el ESP32 deja de escuchar entre paquetes y con hotspots de celular el tablero a veces no respondía. Aumenta el consumo (ver Sección 6.3).
- **Reconexión.** Si la red se cae, el ESP32 intenta reconectarse solo; si en 30 s no lo logra, el firmware reintenta. Al volver la red se reinician el servidor web y el anuncio mDNS, para que recargar la página o abrirla desde otro dispositivo funcione aunque el hotspot se haya reiniciado.
- **Dirección del tablero.** La IP la asigna la WLAN y se muestra en la página 7 del LCD. En un PC también funciona `http://wrews.local` (mDNS); en Android no. Si al reconectar la IP cambia, queda un evento en el tablero.
- **Eventos de red:** conexión (con el nombre de la red y la dirección del tablero), pérdida de la red y número de reconexiones, visibles en el tablero.

---

## 3.16 Tablero de control (Challenge #2)

El tablero es una página web servida por el propio ESP32 (`firmware/wrews/tablero.h`). No usa librerías externas ni CDN, porque la WLAN de la zona puede no tener salida a Internet: las gráficas se dibujan con `<canvas>`.

### Contenido

- **Estado general** (NORMAL, PRECAUCIÓN, CRÍTICO o FALLO) con su color, la severidad de cada variable y el botón **"Silenciar alarma 15 min"**.
- **Tarjetas con el valor actual:** nivel y distancia, tasa de descenso, índice evaporativo, riesgo hídrico, evaporación (mm/día) y radiación neta, irradiancia, temperatura, humedad, presión y VPD (instantáneo y de la ventana). El borde de cada tarjeta toma el color de su severidad.
- **Histórico reciente:** últimos 10 minutos (un punto cada 2 s) de nivel, riesgo, índice evaporativo, tasa, temperatura e irradiancia, con los umbrales de precaución y crítico punteados.
- **Eventos:** cambios de estado, silencios, pérdida y vuelta del Wi-Fi, inicios de sesión, claves incorrectas y cambios de configuración, con su antigüedad. Cada evento nuevo muestra un **aviso** en la parte superior, suena y vibra (después del primer toque en la página).
- **Encabezado y pie:** red, señal (dBm), antigüedad del último dato, tiempo encendido, reconexiones y modo.
- **Configuración y calibración** (Sección 3.17).

### API

| Método y ruta | Uso |
|---|---|
| `GET /` · `GET /login` · `POST /login` · `POST /logout` | Páginas del tablero y sesión |
| `GET /api/actual` | Valor actual de todas las variables (cada 2 s) |
| `GET /api/historial` | Últimos 300 puntos (cada 5 s) |
| `GET /api/eventos?desde=N` | Eventos nuevos (cuando cambia el último evento) |
| `GET /api/config` | Umbrales, pesos y modo, para dibujar las gráficas |
| `POST /api/silenciar` | Silencia el buzzer 15 min |
| `GET` y `POST /api/parametros` · `POST /api/parametros/restaurar` | Calibración |

Cada petición del navegador se cancela si no responde en 4 s (8 s para el historial), y no se lanza una nueva hasta que termina la anterior. Así, cuando la WLAN vuelve después de una caída, el tablero se recupera solo en pocos segundos en lugar de quedar en fila detrás de peticiones colgadas.

### Acceso restringido

El enunciado exige que solo dispositivos **autorizados** y **conectados a la WLAN de la zona** accedan al tablero. Se exigen las dos condiciones:

1. **Misma subred:** el servidor rechaza clientes cuya dirección no esté en la subred del equipo (respuesta 403).
2. **Sesión iniciada:** usuario y contraseña en `/login`. Al validarse, el equipo genera un **token aleatorio de 128 bits** (`esp_random`) que viaja en una cookie `HttpOnly` y `SameSite=Strict`, válida 12 h. Hay hasta 4 sesiones simultáneas; tras **5 claves incorrectas** el inicio de sesión se bloquea 30 s, y cada intento fallido queda como evento.

**Limitación declarada:** el tablero va por HTTP, sin TLS. La clave viaja una sola vez (al iniciar sesión) y solo la protege el cifrado WPA2 de la WLAN. Las sesiones se pierden si el equipo se reinicia.

---

## 3.17 Calibración desde el tablero (Challenge #2)

Los parámetros que dependen del sitio se editan desde la sección "Configuración y calibración" del tablero, se validan en el equipo y se guardan en la flash del ESP32 (`Preferences`/NVS): se conservan aunque el equipo se apague o se reprograme. Se aplican en caliente, sin reiniciar, y cada cambio queda como evento.

| Parámetro | De fábrica | Validación | Ayuda en el tablero |
|---|---|---|---|
| Distancia con el tubo lleno / vacío | 3 / 20 cm | lleno entre 2 y 300 cm; vacío al menos 2 cm mayor que lleno y hasta 400 cm | Muestra la distancia medida en vivo, con botones "Usar como lleno" y "Usar como vacío" |
| K del panel | 10 (W/m²)/mA | 0.5 a 100 | Con una irradiancia de referencia, "Calcular K" la divide por la corriente medida en ese momento |
| Tasa de precaución / crítico | 33 / 68 pp/min | precaución 0.5 a 1000; crítico mayor que precaución | — |
| Salto de discontinuidad | 8 pp | 1 a 100 | — |
| Modo | Demo | Demo o campo | — |
| Ventana demo | 120 s | 30 a 86 400 s | — |
| ET de referencia | 7.5 mm/día | 1 a 20 | — |

Si cambian las distancias, la tendencia de la tasa se reinicia (la escala del nivel cambió); si cambian el modo o la ventana, la estimación de evaporación vuelve a llenarse. Un botón restaura los valores de fábrica. **Los pesos y los umbrales de nivel, riesgo y evaporación no son editables**: están justificados con referencias y solo se cambian en el código.

---

## 3.18 Autodiagnóstico al arrancar (Challenge #2)

Al encender, y antes de empezar a operar, el firmware:

1. Prueba las salidas: LEDs en orden y los dos tonos de alarma (1000 y 2000 Hz).
2. Escanea el bus I²C e identifica LCD, BME280 e INA219.
3. Mide la **corriente del panel en reposo** (promedio de 20 lecturas) y la toma como cero del piranómetro **solo si es menor de 1 mA**; si es mayor, asume que hay luz sobre el panel y deja el cero en 0.
4. Caracteriza el **ruido del sensor de nivel** y calcula la banda muerta de la tasa (Sección 5.5.1).
5. Ejecuta **7 pruebas del modelo de evaporación** contra valores de referencia (Sección 5.7).
6. Carga la calibración guardada en la flash.

Todo queda en el monitor serial como evidencia.

---

## 3.19 Producto terminado: carcasa, alimentación e instalación (Challenge #2)

### Carcasa

Diseñada en CadQuery e impresa en PETG, en seis piezas: prueba de ajuste del tubo, acople al tubo, tapa, caja, piso intermedio y techo del BME280. La caja mide 136 × 110 × 73 mm (interior 130 × 104 × 70 mm). El BME280 va bajo un techo con rejillas, a la sombra y ventilado, como pide la buena práctica meteorológica para medir temperatura y humedad del aire. ⟨completar: versión final impresa, fotos y enlace a los STL⟩.

### Sensor de nivel en tubo

El HC-SR04 va dentro de un tubo de **PVC sanitario de 3"** (diámetro exterior ≈ 82.5 mm) de 40 a 50 cm, con corte recto, borde interior lijado y entradas de agua en la parte inferior. El tubo aísla la medición del oleaje y de reflexiones laterales. El agua no debe subir a menos de **5 cm** del sensor (zona ciega), por lo que la distancia de "lleno" se calibra a 5 cm o más.

### Alimentación

| Rama | Desde | Alimenta |
|---|---|---|
| Pilas | Portapilas 4×AA → interruptor | Pin `VIN` del ESP32 y fila de 5 V |
| 5 V | `VIN` | HC-SR04, buzzer, LEDs, LCD |
| 3.3 V | Pin `3V3` del ESP32 | BME280, INA219 |

⟨completar: tipo de pilas usado finalmente y, si son alcalinas (≈ 6 a 6.4 V nuevas), los 2 diodos 1N4007 en serie y la tensión medida en la fila de 5 V⟩. Para programar por USB, el interruptor va en OFF.

### Mapa de pines (ESP32 DevKit de 38 pines)

| Pin ESP32 | Conectado a | Función |
|---|---|---|
| `GPIO 21 (SDA)` · `GPIO 22 (SCL)` | BME280, INA219, LCD | Bus I²C |
| `GPIO 5` | TRIG del HC-SR04 | Disparo del pulso ultrasónico |
| `GPIO 18` | ECHO del HC-SR04 | Recepción del eco ⟨confirmar si lleva divisor resistivo⟩ |
| `GPIO 25` · `GPIO 26` · `GPIO 27` | LED verde · amarillo · rojo (ánodo común) | Estado |
| `GPIO 19` | Buzzer pasivo | Alarma sonora (PWM) |
| `VIN` · `3V3` · `GND` | Ver tabla de alimentación | Alimentación y tierra común |

En el Challenge #2 se retiró el botón físico de silencio del Challenge #1: el silencio se hace desde el tablero.

---

## 3.20 Trazabilidad Wiki ↔ código

Todos los valores de esta Wiki salen de `firmware/wrews/wrews.ino` (firmware v7). La tabla indica el nombre de cada constante o función, para buscarla en el código (los números de línea cambian entre versiones). Las marcadas como editables se cambian desde el tablero y se guardan en la flash; el valor indicado es el de fábrica.

| Concepto | Constante / función | Valor | Sección |
|---|---|---|---|
| Distancias de lleno / vacío (editables) | `D_LLENO_DEF`, `D_VACIO_DEF` | 3 / 20 cm | 3.2.1, 3.17 |
| Mediana del ultrasónico | `leerDistancia()` | 5 ecos, velocidad del sonido 343 m/s | 3.6 |
| Constante del panel (editable) | `K_PANEL_DEF` | 10 (W/m²)/mA | 3.2.3 |
| Cero del panel | `OFFSET_MAX_MA` | solo si < 1 mA | 3.18, 5.5.1 |
| Priestley-Taylor | `priestleyTaylor()`, `ALPHA_PT` | α = 1.26 | 3.2.3 |
| Albedo, λ, σ | `ALBEDO_AGUA`, `LAMBDA_MJ_KG`, `SIGMA_MJ` | 0.06, 2.45 MJ/kg, 4.903·10⁻⁹ | 3.2.3 |
| Altitud y Ra | `ALTITUD_M`, `RA_FIJO_MJ` | 2560 m, 36 MJ/m²·día | 3.2.3 |
| ET de referencia (editable) | `ET_REF_DEF` | 7.5 mm/día | 3.2.3 |
| Ventana de evaporación | `VENTANA_CAMPO_S`, `VENTANA_DEMO_DEF` (editable), `NUM_BUCKETS`, `COBERTURA_MIN` | 24 h, 120 s, 24, 50 % | 3.2.3 |
| Modo demo (índice de claridad) | `evaluarVentana()`, `gPicoDespejado()`, `N_HORAS_SOL` | G_pico ≈ 1049 W/m², 12 h | 3.2.3 |
| Índice evaporativo | `indiceEvaporativo()`, `W_PT`, `W_VPD`, `VPD_REF_KPA` | 0.7 / 0.3, 2.0 kPa | 3.2.3 |
| Tasa de descenso | `calcularTasa()`, `VENTANA_N`, `MIN_MUESTRAS`, `TASA_REF` | 20 muestras, 6 mínimas, 100 pp/min | 3.2.4 |
| Banda muerta | `caracterizarRuido()`, `BANDA_MANUAL` | 3·SE; respaldo 5 pp/min | 3.2.4, 5.5.1 |
| Salto de discontinuidad (editable) | `SALTO_DEF` | 8 pp | 3.2.4 |
| Pesos del riesgo | `W_NIVEL`, `W_EVAP`, `W_TASA` | 0.54 / 0.30 / 0.16 | 3.2.5 |
| Umbrales de nivel | `U_PREC_NIVEL`, `U_CRIT_NIVEL` | 50 / 15 % | 3.2.7 |
| Umbrales de riesgo | `U_PREC_RIESGO`, `U_CRIT_RIESGO` | 36.2 / 69.2 | 3.2.7 |
| Umbrales de evaporación | `U_PREC_EVAP`, `U_CRIT_EVAP` | 60 / 85 | 3.2.7 |
| Umbrales de tasa (editables) | `U_PREC_TASA_DEF`, `U_CRIT_TASA_DEF` | 33 / 68 pp/min | 3.2.7 |
| Tope de la evaporación | `calcularObjetivo()` (`s_evap_estado`) | máximo PRECAUCIÓN | 3.2.6 |
| Escalera y confirmación | `aplicarEstado()`, `CONF_SUBIR`, `CONF_BAJAR` | 2 / 3 ciclos | 3.2.8 |
| Periodo de medición | `T_MUESTREO_MS`, `tareaMedicion()` | 1 s | 3.14 |
| Patrones de alarma | `PAT`, `BUZ_HZ`, `tareaAlarmas()` | 1000 / 2000 / 600 Hz | 3.8 |
| Silencio | `silenciarAlarma()`, `SILENCIO_MS` | 15 min | 3.8, 3.16 |
| Historial del tablero | `N_HIST`, `HIST_CADA` | 300 puntos, 1 cada 2 s | 3.16 |
| Sesiones | `SESION_MS`, `N_SESIONES`, `MAX_FALLOS_LOGIN`, `BLOQUEO_LOGIN_MS` | 12 h, 4, 5 intentos, 30 s | 3.16 |
| Reconexión Wi-Fi | `vigilarWiFi()`, `WIFI_REINTENTO_MS` | 30 s | 3.15 |
| Calibración en flash | `cargarParametros()`, `guardarParametros()`, `validarParametros()` | — | 3.17 |

---

[⬅ Anterior: Solución propuesta](02-Solucion-Propuesta.md) · [⬆ Índice](00-Home.md) · [Siguiente: Modelo de negocio ➡](04-Modelo-de-Negocio.md)

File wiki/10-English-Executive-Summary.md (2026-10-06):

[⬅ Back to index](00-Home.md)

# 10. English Executive Summary

## WREWS — Water Risk Early Warning System

**WREWS (Water Risk Early Warning System)** is a low-cost IoT prototype designed to monitor water availability and generate early local warnings when conditions associated with water-scarcity risk are detected.

The system is built around an **ESP32** and combines three main dimensions:

1. **Current water availability**, estimated from the reservoir level.
2. **Environmental conditions favorable to evaporation**, derived from temperature, relative humidity, and estimated solar irradiance.
3. **Water-level trend**, obtained by analyzing the rate at which the level decreases over time.

Rather than relying on a single measurement, WREWS fuses these signals into a **water-risk index** and classifies the situation into three easily understandable states:

- 🟢 **NORMAL**
- 🟡 **PRECAUTION**
- 🔴 **CRITICAL**

In **Challenge #2** the prototype became a **finished, enclosed, battery-powered device** that, in addition to the local alarm, hosts a **web dashboard** on an embedded web server inside the ESP32. The dashboard is reachable only from the local WLAN provided by the authorities and only after logging in. It shows current values and recent history, notifies every state change, lets authorities silence the physical alarm, and allows calibration without opening the enclosure. The evaporative index was replaced by **Priestley-Taylor potential evaporation with FAO-56 parameters**, and the weights and thresholds are now anchored to cited methods and regulations.

---

## System architecture

The physical prototype integrates:

- **ESP32** as the central processing unit.
- **OKY3261/HC-SR04 ultrasonic sensor** for water-level estimation.
- **BME280** for temperature, relative humidity, and atmospheric pressure.
- **Mini photovoltaic panel + INA219** for experimental solar-irradiance estimation.
- **16×2 I²C LCD** for local visualization.
- **Green, yellow, and red LEDs** for status indication.
- **Buzzer** for critical audible warnings.

All sensing, processing, risk classification, and actuation are performed **locally on the ESP32**.

Therefore, WREWS does not depend on Wi-Fi, cellular networks, cloud services, or any external communication infrastructure to generate an alert.

Since Challenge #2, the firmware runs on three FreeRTOS threads: measurement on core 0, alarms on core 1, and the web server, Wi-Fi and LCD in the main loop. Two mutexes protect the shared state and the I²C bus. Because the alarms run in their own task, a slow browser or a WLAN outage cannot freeze the physical alarm.

---

## Data fusion

The water-risk model combines three components:

```text
Water-level deficit              54 %
Evaporative conditions           30 %
Level-decrease trend             16 %
```

The weights are the priority vector obtained with Saaty's **Analytic Hierarchy Process** (consistency ratio 0.008); Challenge #1 used the rounded 50/30/20.

Conceptually:

```text
WATER LEVEL
     ↓
LEVEL DEFICIT ─────────── 54 % ──┐
                                  │
TEMPERATURE + HUMIDITY            │
     ↓                            │
    VPD                           ├──→ WATER-RISK INDEX
     +                            │
ESTIMATED IRRADIANCE              │
     ↓                            │
EVAPORATIVE INDEX ─────── 30 % ───┤
                                  │
LEVEL OVER TIME                   │
     ↓                            │
DECREASE RATE ─────────── 16 % ───┘
```

The weighted index is complemented by **independent safety rules**, allowing an extreme individual condition to escalate the system state even when the weighted average has not yet reached the critical threshold. The one exception, introduced in Challenge #2, is evaporation: on its own it can raise the state only up to PRECAUTION, because a sunny, dry noon with a full reservoir is not an emergency. It still feeds the combined risk with its weight, so a low level plus high evaporation does reach CRITICAL.

| Variable | PRECAUTION | CRITICAL | Source |
|---|---|---|---|
| Level | ≤ 50 % | ≤ 15 % | Spanish Drought Management Plans (pre-alert 0.50, emergency 0.15) |
| Evaporative index | ≥ 60 | ≥ 85 (severity only) | Assumption; to be closed with local climatological percentiles |
| Decrease rate | ≥ 33 pp/min | ≥ 68 pp/min | Experimental calibration |
| Combined risk | ≥ 36.2 | ≥ 69.2 | Derived from the level thresholds |

---

## Environmental analysis

Temperature and relative humidity measured by the BME280 are used to calculate **Vapor Pressure Deficit (VPD)**.

VPD provides an indicator of how favorable atmospheric conditions are for evaporation.

The photovoltaic panel and INA219 provide an electrical signal related to the amount of radiation received. This signal is used as an **experimental estimate of solar irradiance**.

In Challenge #2, the evaporative index is built on the **Priestley-Taylor** equation, λET = α·Δ/(Δ+γ)·(Rn − G), with net radiation, Δ and γ computed with **FAO-56**. The model runs over a moving window of measurements (24 h in field mode; in demo mode a short window whose average light is treated as the noon of a day with that cloudiness, using the clearness index). The resulting daily evaporation is normalized against a clear day at the site (7.5 mm/day) and combined with the window's VPD:

```text
Evaporative index = 70 · min(ET / 7.5, 1) + 30 · min(VPD / 2.0, 1)
```

This index does not represent the actual percentage of water evaporated. Instead, it indicates how favorable the environmental conditions are for evaporation.

Atmospheric pressure is also measured by the BME280. It is not used as a risk indicator — in a fixed tropical station its variation is negligible and it does not respond to water scarcity. Instead, it acts as a **parameter of the evaporation model**: through the psychrometric constant γ = 0.665·10⁻³·P, the measured pressure sets the Priestley-Taylor term Δ/(Δ+γ) directly, replacing the fixed altitude factor used in Challenge #1.

---

## Level trend

WREWS also analyzes multiple water-level measurements over time.

This makes it possible to estimate the **rate of level decrease** and distinguish between two reservoirs that may currently have the same level but are evolving differently.

For example:

```text
Reservoir A
Level: 50 %
Decrease rate: low
→ relatively stable

Reservoir B
Level: 50 %
Decrease rate: high
→ water availability is declining rapidly
```

This trend analysis adds an early-warning component to the system.

---

## Local warning system

After processing the available information, WREWS classifies the situation and activates the corresponding local indicators:

```text
NORMAL
→ Green LED
→ LCD status
→ Buzzer off

PRECAUTION
→ Yellow LED
→ LCD status

CRITICAL
→ Red LED
→ LCD status
→ Audible buzzer warning
```

The **16×2 I²C LCD** provides local information about the system, while the LEDs make the current state immediately recognizable.

---

## Web dashboard (Challenge #2)

The ESP32 joins the local WLAN in station mode and serves a dashboard with no external libraries or cloud services. It provides:

- current values of all variables, color-coded by severity;
- a 10-minute history chart for level, risk, evaporative index, decrease rate, temperature and irradiance, with dashed threshold lines;
- an event log with on-screen, sound and vibration notifications for every state change;
- a button to silence the buzzer for 15 minutes (the LEDs keep showing the state);
- a calibration panel (tank full/empty distances, panel constant, rate thresholds, demo or field mode), stored in the ESP32 flash.

Access requires both being on the same subnet as the device and an authenticated session (random 128-bit token in an HttpOnly cookie, lockout after 5 failed attempts). As a declared limitation, the dashboard uses HTTP without TLS.

---

## Validation

The development and validation process was divided into two stages.

### Stage 1 — Wokwi simulation

The system was initially developed and tested in Wokwi.

The simulation allowed the team to:

- validate the system architecture;
- test sensor acquisition;
- verify I²C communication;
- evaluate the mathematical processing;
- reproduce controlled environmental scenarios;
- validate NORMAL, PRECAUTION, and CRITICAL states;
- debug the firmware before physical integration.

Custom simulation components were used for some sensors and signals.

### Stage 2 — Physical prototype

After the simulation stage, WREWS was assembled and tested as a **functional physical prototype**.

A movable platform was incorporated into the scale model to represent the water surface.

Changing the platform height modifies the distance measured by the ultrasonic sensor, allowing different reservoir levels to be reproduced safely and repeatedly without exposing the electronics directly to water.

Physical testing confirmed the operation of:

- ultrasonic level sensing;
- BME280 environmental acquisition;
- photovoltaic panel and INA219 acquisition;
- local processing on the ESP32;
- level-decrease analysis;
- risk classification;
- 16×2 I²C LCD;
- status LEDs;
- critical buzzer alarm.

The physical implementation therefore validated the complete chain:

```text
SENSING
   ↓
ACQUISITION
   ↓
PROCESSING
   ↓
DATA FUSION
   ↓
RISK CLASSIFICATION
   ↓
LOCAL WARNING
```

### Stage 3 — Challenge #2 test bench

The finished device was tested outdoors in the sun, following the minimum blocks required by the brief: calibration against reference instruments, accelerated emulation (draining the tube, sun and shade on the panel, a hair dryer on the BME280), validation of the fusion logic and thresholds, notification tests (dashboard updates, alerts, silencing the alarm from the dashboard), and robustness tests (WLAN loss and reconnection, restricted access). An on-board self-test checks the evaporation model against independently computed reference values at every start-up. These tests revealed and fixed four real issues: saturation of the evaporative index in full sun, false CRITICAL alarms caused by evaporation alone with a full reservoir, a dashboard that did not recover after a WLAN outage, and a critical-alarm tone (2500 Hz) above the buzzer's usable range (now 2000 Hz).

### Experimental characterization

Before fixing the trend-detection parameters, the ultrasonic sensor's noise was characterized experimentally: with the platform stationary, 20 measurements were taken and their standard deviation computed. From this, the standard error of a
least-squares slope over the estimation window was derived, and the dead band was set at three times that value — keeping the false-positive rate below 1 %. This characterization runs automatically at every startup, so the dead band adapts to the specific installation rather than relying on a fixed a-priori value.

The trend thresholds were then calibrated using two controlled descent manoeuvres, yielding maximum slopes of **46.9 pp/min** (slow) and **98.2 pp/min** (fast). The precaution threshold was set at 70 % of the slow manoeuvre and the critical threshold at the geometric mean of both, which leaves the same relative margin on either side.

---

## Conclusion

WREWS demonstrates how a low-cost IoT system can combine **water level, environmental conditions, and level trend** to provide a more comprehensive assessment of water-scarcity risk.

The final result is a functional physical prototype capable of acquiring multiple variables, processing them locally on an ESP32, and translating the information into three clear warning states.

The project demonstrates the complete transition from **sensing to decision and local actuation**, providing a functional proof of concept for an early water-risk warning system.

In Challenge #2, WREWS evolved into an enclosed, battery-powered device with a secure local web dashboard, a physically based evaporation model, and weights and thresholds traceable to published methods and regulations.

---

[⬅ Previous: Team and roles](09-Equipo-Roles.md) · [⬆ Index](00-Home.md)

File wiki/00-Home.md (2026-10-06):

# Wiki — WREWS (Water Risk Early Warning System)

**Curso:** Internet de las Cosas — 2026-2
**Facultad de Ingeniería — Universidad de La Sabana**
**Challenge #2 — Equipo 2** (evolución del prototipo del Challenge #1)
**Fecha de entrega:** ⟨completar⟩ · **Sustentación:** ⟨completar⟩
*Challenge #1: entrega el 22 de agosto de 2026 · sustentación en la semana 6 (24 o 27 de agosto de 2026)*

Bienvenidos a la Wiki técnica del proyecto **WREWS (Water Risk Early Warning System)**, un prototipo IoT de bajo costo, basado en ESP32, que monitorea de forma continua el nivel de un reservorio de agua, las condiciones ambientales que favorecen su evaporación y la velocidad de descenso del nivel, fusionando estas señales en un único **índice de riesgo hídrico** que se comunica localmente mediante una pantalla LCD 16×2 I²C, LEDs de estado y un buzzer.
El desarrollo se realizó en dos etapas: primero se validó la arquitectura y la lógica del sistema mediante simulación en Wokwi y posteriormente se construyó y validó un prototipo físico funcional. La implementación física final utiliza una pantalla LCD 16×2 I²C como interfaz de visualización local.

En el **Challenge #2** el prototipo pasa a ser un **dispositivo autónomo en carcasa**, alimentado por pilas, que además de la alarma local publica un **tablero de control web** alojado en el propio ESP32 y accesible solo desde la WLAN de la zona y con usuario y contraseña. El tablero muestra el valor actual y el histórico reciente de las variables, notifica los cambios de estado, permite silenciar la alarma física y calibrar el equipo sin abrir la carcasa. El índice evaporativo se reemplazó por la **evaporación potencial de Priestley-Taylor con parámetros FAO-56**, y los pesos y umbrales se anclaron a métodos y normativa citados (ver [Mejoras respecto al Challenge #1](12-Mejoras-Challenge-1.md)).

## 🎥 Video de demostración

▶️ **[Ver video de demostración de WREWS (Challenge #2)](https://youtu.be/H0U9AYJEdTg)**

El funcionamiento completo del prototipo físico WREWS del Challenge #1, incluyendo la adquisición de variables, procesamiento y generación de los estados **NORMAL, PRECAUCIÓN y CRÍTICO**, puede observarse en el video final:

▶️ **[Ver video de demostración de WREWS (Challenge #1)](https://youtu.be/zUS3DWeHSsw)**

---

## Índice

1. [Resumen, motivación y justificación](01-Resumen-Motivacion.md)
2. [Solución propuesta: restricciones, arquitectura y diagrama de bloques](02-Solucion-Propuesta.md)
3. [Desarrollo modular: criterios de diseño, UML, esquemático y estándares](03-Desarrollo-Modular.md)
4. [Modelo de negocio](04-Modelo-de-Negocio.md)
5. [Configuración experimental, resultados y análisis](05-Configuracion-Experimental-Resultados.md)
6. [Autoevaluación del protocolo de pruebas](06-Autoevaluacion-Pruebas.md)
7. [Conclusiones, retos, trabajo futuro y referencias](07-Conclusiones-Trabajo-Futuro.md)
8. [Uso de Inteligencia Artificial](08-Uso-de-IA.md)
9. [Equipo de trabajo: roles y contribuciones](09-Equipo-Roles.md)
10. [Executive Summary (English)](10-English-Executive-Summary.md)
11. [Conectividad‐IoT](11-Conectividad-IoT.md)
12. [Mejoras respecto al Challenge #1](12-Mejoras-Challenge-1.md)

## Anexos

- Código fuente completo y documentado (firmware v7): [`/firmware/wrews/wrews.ino`](https://github.com/jorgis857/sistema-alerta-temprana-riesgo-hidrico/blob/main/firmware/wrews/wrews.ino)
- Páginas del tablero de control (inicio de sesión y tablero): [`/firmware/wrews/tablero.h`](https://github.com/jorgis857/sistema-alerta-temprana-riesgo-hidrico/blob/main/firmware/wrews/tablero.h)
- Plantilla de credenciales de la WLAN y del tablero: [`/firmware/wrews/secrets.example.h`](https://github.com/jorgis857/sistema-alerta-temprana-riesgo-hidrico/blob/main/firmware/wrews/secrets.example.h)
- Librerías utilizadas: [`/firmware/libraries.txt`](https://github.com/jorgis857/sistema-alerta-temprana-riesgo-hidrico/blob/main/firmware/libraries.txt)
- Diagrama de conexión Wokwi (Challenge #1): [`/hardware/wokwi/diagram.json`](https://github.com/jorgis857/sistema-alerta-temprana-riesgo-hidrico/blob/main/hardware/wokwi/diagram.json)
- Chips personalizados (BME280, INA219, panel solar): [`/hardware/wokwi/chips`](https://github.com/jorgis857/sistema-alerta-temprana-riesgo-hidrico/tree/main/hardware/wokwi/chips)
- Esquemático / captura del circuito: [`/hardware/schematics/diagrama_circuito_wokwi.png`](https://github.com/jorgis857/sistema-alerta-temprana-riesgo-hidrico/blob/main/hardware/schematics/diagrama_circuito_wokwi.png)
- Proyecto simulable en Wokwi (firmware del Challenge #1): <https://wokwi.com/projects/472250559337371649>
- Modelos 3D de la carcasa: ⟨completar: enlace a los STL / script CadQuery de la versión final⟩

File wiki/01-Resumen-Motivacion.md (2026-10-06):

[⬅ Volver al índice](00-Home.md)

# 1. Resumen general, motivación, justificación y estructura de la documentación

## 1.1 Resumen ejecutivo

**WREWS (Water Risk Early Warning System)** es un prototipo funcional de Internet de las Cosas construido sobre un microcontrolador **ESP32**, diseñado para monitorear en tiempo real la disponibilidad de agua en puntos críticos de suministro y almacenamiento (aljibes, tanques comunitarios, reservorios veredales) de la región Sabana Centro (Cundinamarca), y para **alertar de forma local e inmediata** — sin depender de Internet, Wi-Fi, redes celulares ni ningún otro medio de comunicación — cuando las condiciones se acercan a un escenario de desabastecimiento.

En el **Challenge #2** el mismo nodo se convierte en un dispositivo autónomo, en carcasa y alimentado por pilas, que además publica un **tablero de control web** en la WLAN que las autoridades locales ponen a disposición en la zona. El tablero se aloja en un servidor web embebido en el propio ESP32 (sin nube ni MQTT), solo es accesible desde esa WLAN y con usuario y contraseña, y muestra el valor actual y el histórico reciente de las variables, avisa de cada cambio de estado y permite silenciar la alarma física. La alarma local sigue siendo independiente de la red: si la WLAN se cae, el equipo sigue midiendo y alarmando.

El sistema combina tres tipos de evidencia física para tomar una decisión de riesgo:

1. **Cuánta agua queda** — nivel del reservorio, medido con un sensor ultrasónico HC-SR04.
2. **Qué tan favorables son las condiciones ambientales para que esa agua se pierda por evaporación** — estimando la evaporación potencial diaria con el modelo de **Priestley-Taylor** y parámetros **FAO-56**, a partir de la radiación solar (mini panel solar + sensor de corriente INA219) y de la temperatura, humedad relativa y presión (sensor BME280), complementada con el déficit de presión de vapor.
3. **Qué tan rápido está bajando el nivel** — estimando la pendiente del nivel por regresión sobre una ventana de mediciones.

Estas tres señales se funden mediante una función de ponderación (54 % déficit de nivel + 30 % índice evaporativo + 16 % tasa de descenso, obtenida con el método AHP) más un conjunto de **reglas de seguridad** que garantizan que ninguna variable extremadamente crítica quede "escondida" por el promedio de las demás. El resultado se traduce en tres estados — 🟢 `NORMAL`, 🟡 `PRECAUCIÓN`, 🔴 `CRÍTICO` — que se comunican **in situ** mediante una pantalla LCD 16×2 I²C, LEDs de estado y un buzzer, y en el tablero de control web.

## 1.2 Motivación

Durante 2026, el Gobierno Nacional y el IDEAM confirmaron el inicio anticipado del Fenómeno de El Niño, lo que agravó de forma crítica la disponibilidad hídrica en la Sabana de Bogotá y Cundinamarca [1]. La CAR identificó **20 municipios** de la región en riesgo extremo de desabastecimiento hídrico e incendios forestales por el agotamiento físico de fuentes superficiales y reservorios locales [2]. A esto se suman 16 escenarios de riesgo crítico tipificados por las autoridades distritales, entre los cuales el desabastecimiento crónico de agua potable y la caída de niveles en embalses ocupan un lugar central [3]. Aunque existen planes de contingencia institucionales [4], estos dependen de redes de monitoreo hidrometeorológico centralizadas que no necesariamente llegan con la granularidad y la velocidad de reacción que requieren los reservorios comunitarios rurales más pequeños y dispersos.

De ahí nace la motivación del proyecto: **llevar la vigilancia hidrometeorológica al punto exacto donde el agua se almacena**, con un dispositivo autónomo, de bajo costo, que no dependa de conectividad, y que traduzca variables físicas crudas en una alerta comprensible para cualquier persona de la comunidad — sin necesidad de interpretar datos técnicos.

## 1.3 Justificación

- **Pertinencia social:** los reservorios comunitarios y aljibes rurales de Sabana Centro son gestionados frecuentemente por juntas de acueductos veredales con recursos técnicos limitados; un sistema de bajo costo con alerta visual/sonora directa es más accesible que un sistema que dependa de una app o de conectividad a Internet.
- **Pertinencia técnica (IoT):** el reto exige aplicar los pilares de un ecosistema IoT — percepción (sensores ambientales e hidráulicos), procesamiento en el borde (*edge computing* en el ESP32, sin nube), fusión de datos multivariable y actuación local (HMI física) — todo dentro de un mismo nodo autónomo.
- **Restricción de comunicaciones:** al no poder usarse redes de comunicación convencionales, el diseño obliga a que **toda la inteligencia de decisión resida en el dispositivo**, lo cual es un ejercicio representativo de sistemas embebidos distribuidos ("edge intelligence") aplicables a zonas rurales sin cobertura. En el Challenge #2 se suma un tablero en la WLAN local, pero la decisión y la alarma siguen ocurriendo en el dispositivo: la red solo lleva la información a las autoridades, no es necesaria para alertar.
- **Escalabilidad:** el mismo firmware y arquitectura de sensores puede replicarse en distintos puntos críticos (aljibes, tanques de distrito de riego, quebradas) simplemente recalibrando las distancias de lleno y vacío de cada reservorio, que en el Challenge #2 se ajustan desde el tablero de control sin reprogramar el equipo.

## 1.4 Alcance del prototipo

El prototipo se validó primero en simulación mediante **Wokwi**, utilizando *custom chips* en lenguaje C que emulan de forma funcional el comportamiento físico de un sensor BME280 (temperatura, humedad, presión), un sensor de corriente INA219 conectado a un mini panel solar (radiación solar aproximada), y un sensor ultrasónico HC-SR04 (nivel del reservorio). Para el Challenge #1 se construyó un prototipo físico sobre una maqueta con plataforma móvil.

En el Challenge #2 el alcance es un **prototipo de producto terminado**: el ESP32, los sensores, la alarma y la alimentación por pilas se integran en una carcasa impresa en 3D, con el sensor de nivel dentro de un tubo de PVC que se instala en el punto de almacenamiento, y con el tablero de control web en la WLAN de la zona. El firmware corre completamente en el ESP32 y no requiere ningún servicio externo.

## 1.5 Estructura de la documentación

Esta Wiki sigue la estructura solicitada en el enunciado del Challenge #2:

| Sección | Contenido |
|---|---|
| [2. Solución propuesta](02-Solucion-Propuesta.md) | Restricciones de diseño identificadas y arquitectura (diagrama de bloques hardware/software) |
| [3. Desarrollo modular](03-Desarrollo-Modular.md) | Criterios de diseño, diagramas UML, esquemático de hardware, estándares de ingeniería aplicados |
| [4. Modelo de negocio](04-Modelo-de-Negocio.md) | Business Model Canvas del sistema |
| [5. Configuración experimental, resultados y análisis](05-Configuracion-Experimental-Resultados.md) | Casos de prueba, mediciones y su interpretación |
| [6. Autoevaluación del protocolo de pruebas](06-Autoevaluacion-Pruebas.md) | Checklist de validación del propio protocolo |
| [7. Conclusiones, retos, trabajo futuro y referencias](07-Conclusiones-Trabajo-Futuro.md) | Cierre del proyecto y bibliografía IEEE |
| [8. Uso de Inteligencia Artificial](08-Uso-de-IA.md) | Declaración obligatoria de uso de IA generativa |
| [9. Equipo de trabajo](09-Equipo-Roles.md) | Roles, actividades y contribuciones de cada integrante |
| [10. Executive Summary](10-English-Executive-Summary.md) | Resumen del proyecto en inglés |
| [11. Conectividad IoT](11-Conectividad-IoT.md) | Actividad de refuerzo #2.3: red distribuida de nodos con MQTT |
| [12. Mejoras respecto al Challenge #1](12-Mejoras-Challenge-1.md) | Cómo se atendieron las deficiencias y la retroalimentación del Challenge #1 |

---
[⬅ Volver al índice](00-Home.md) · [Siguiente: Solución propuesta ➡](02-Solucion-Propuesta.md)

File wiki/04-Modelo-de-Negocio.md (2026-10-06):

[⬅ Volver al índice](00-Home.md)

# 4. Modelo de negocio

Aunque el proyecto nace como un reto académico, se plantea un modelo de negocio orientado a un despliegue real por parte de acueductos veredales, alcaldías municipales y la CAR Cundinamarca, bajo un esquema de **hardware de bajo costo + servicio de instalación/mantenimiento**, sin necesidad de conectividad ni suscripción a la nube (lo cual reduce drásticamente el costo operativo frente a soluciones IoT tradicionales basadas en la nube).

## 4.1 Business Model Canvas

| Bloque | Contenido |
|---|---|
| **Segmentos de clientes** | (1) Juntas administradoras de acueductos veredales de Sabana Centro. (2) Alcaldías municipales y Unidades de Gestión del Riesgo de Desastres (UGRD). (3) Distritos de riego agroindustriales. (4) CAR Cundinamarca (monitoreo distribuido complementario a su red institucional). |
| **Propuesta de valor** | Alerta temprana de riesgo hídrico **in situ**, sin dependencia de redes de comunicación ni de conectividad a Internet; instalación simple, bajo costo (< USD 50 en componentes), calibración replicable en distintos reservorios, y visualización comprensible para personal no técnico. Desde el Challenge #2, además, un **tablero de control web** en la WLAN local de la autoridad (sin nube ni suscripción) con valor actual, histórico, avisos, silencio de la alarma y calibración remota sin abrir el equipo. |
| **Canales** | Instalación directa por parte del equipo/empresa derivada del proyecto; alianzas con la CAR y alcaldías para despliegue en puntos críticos priorizados; difusión mediante juntas de acción comunal. |
| **Relación con el cliente** | Instalación asistida + capacitación inicial a la comunidad + mantenimiento preventivo periódico (limpieza de sensores, recalibración estacional, reemplazo de batería). |
| **Fuentes de ingreso** | Venta del kit de hardware ensamblado; contrato de mantenimiento anual; servicio de calibración por punto de instalación; posibles convenios institucionales (CAR, alcaldías) para despliegue masivo subsidiado. |
| **Recursos clave** | Firmware propio (lógica de fusión validada), diseño de hardware replicable, conocimiento del dominio hidrológico regional, relación con actores institucionales locales. |
| **Actividades clave** | Ensamblaje y calibración de nodos, instalación en campo, soporte técnico, actualización del firmware, generación de reportes agregados de riesgo regional (offline, por recolección manual de datos si se requiere históricos). |
| **Socios clave** | CAR Cundinamarca, IDEAM, alcaldías de Sabana Centro, proveedores de componentes electrónicos, juntas de acueductos veredales, Universidad de La Sabana (transferencia de conocimiento). |
| **Estructura de costos** | Componentes electrónicos por unidad (ESP32, sensores, LCD 16×2 I²C, batería, panel solar), carcasa/impermeabilización, mano de obra de ensamblaje e instalación, mantenimiento periódico, capacitación comunitaria. |
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

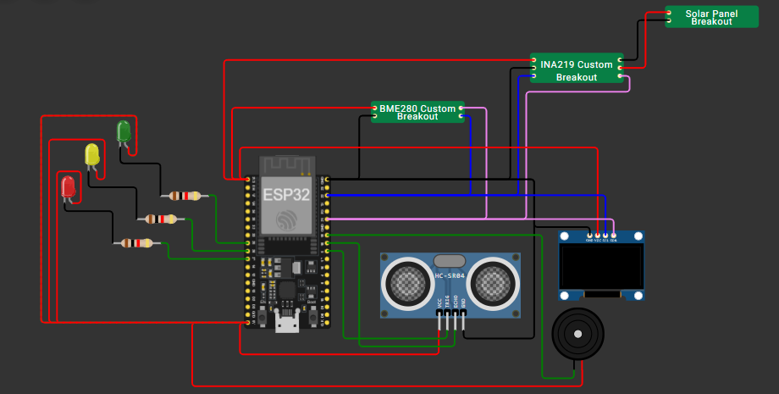
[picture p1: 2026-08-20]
hardware/schematics/diagrama_circuito_wokwi.png

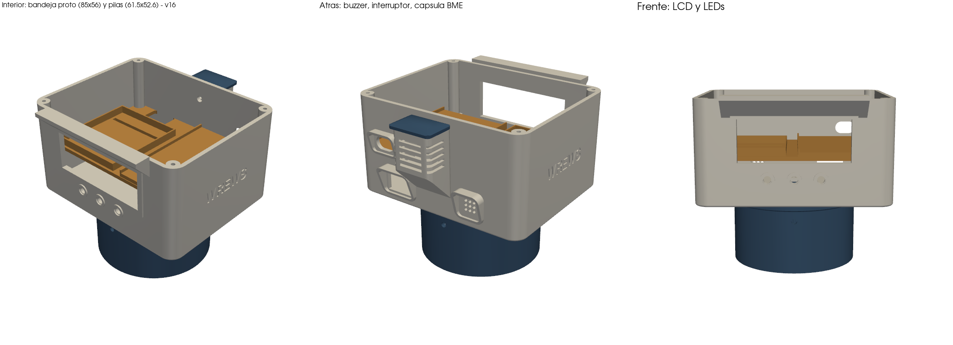
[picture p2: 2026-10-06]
Carcasa_3D_/Carcasa_3D_v16/preview/v16_check.png

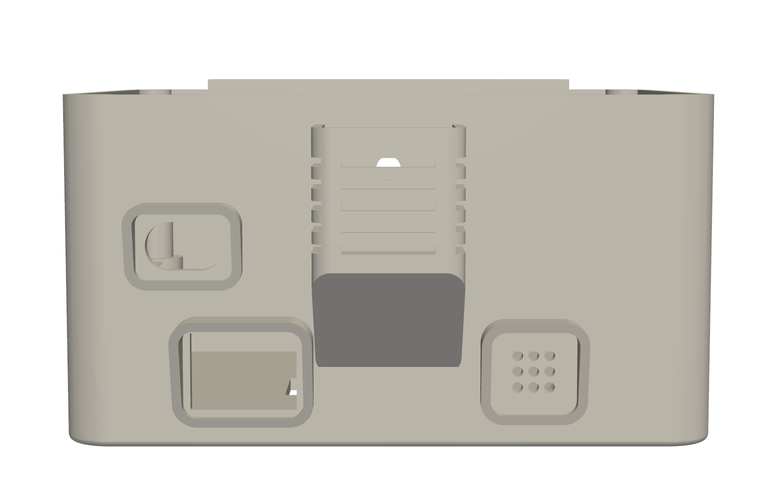
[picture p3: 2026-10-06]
Carcasa_3D_/Carcasa_3D_v16/preview/v16_atras.png

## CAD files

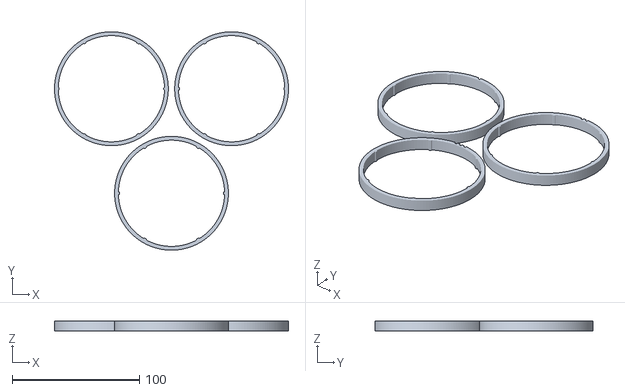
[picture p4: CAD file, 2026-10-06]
Carcasa_3D_/Carcasa_3D_v16/stl/1_prueba_ajuste_tubo.stl
184.1 x 171.8 x 8.00

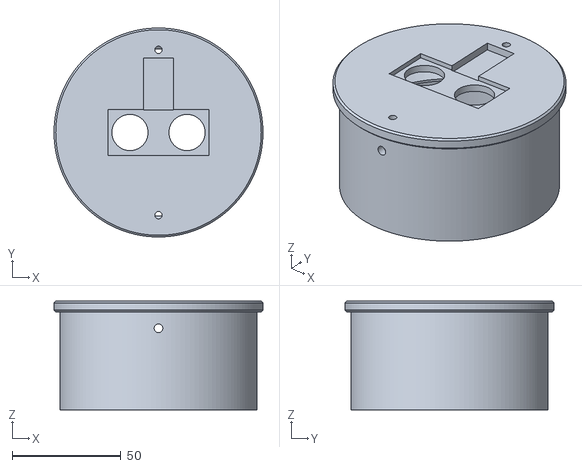
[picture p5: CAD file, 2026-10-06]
Carcasa_3D_/Carcasa_3D_v16/stl/2_acople_tubo.stl
96.0 x 96.0 x 50.0

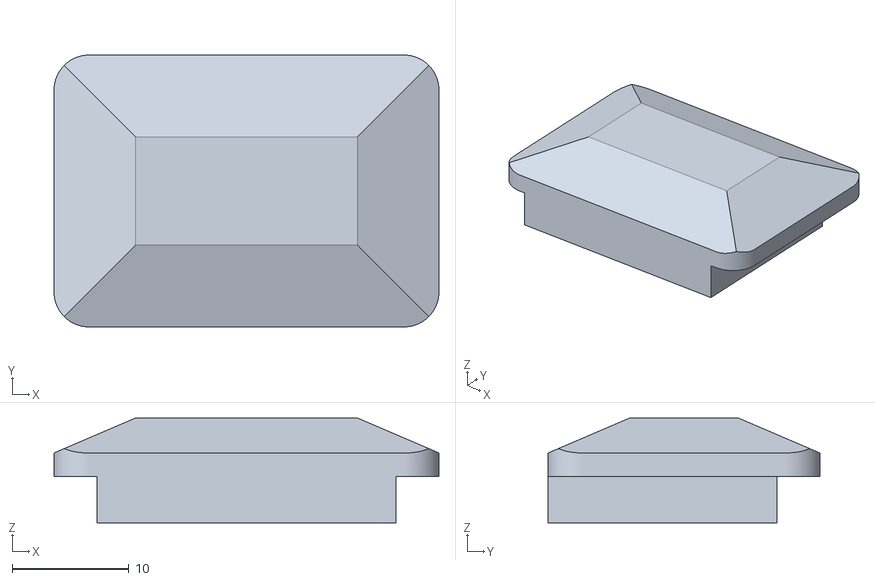
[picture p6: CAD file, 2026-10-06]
Carcasa_3D_/Carcasa_3D_v16/stl/6_techo_bme.stl
33.0 x 23.3 x 9.00

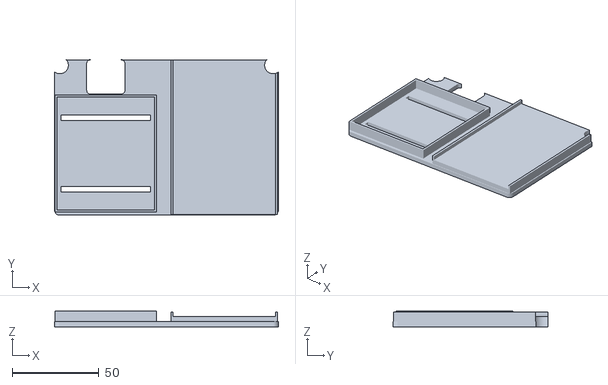
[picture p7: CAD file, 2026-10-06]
Carcasa_3D_/Carcasa_3D_v16/stl/5_piso_intermedio.stl
129.2 x 89.6 x 9.00

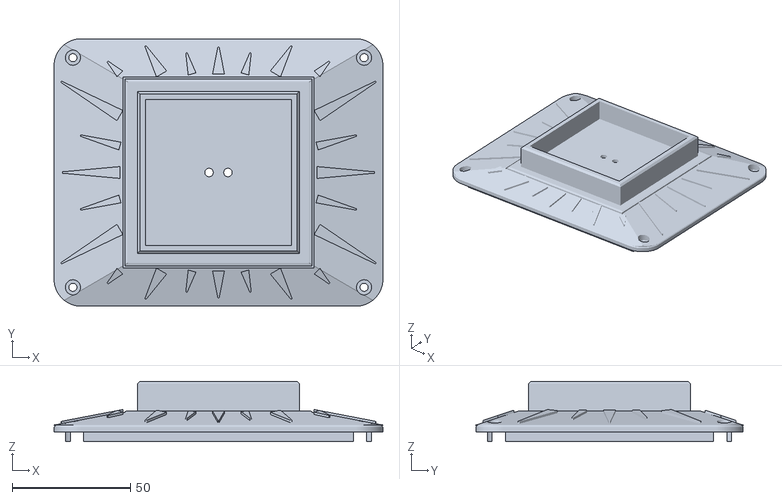
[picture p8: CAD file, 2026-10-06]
Carcasa_3D_/Carcasa_3D_v16/stl/3_tapa.stl
139.0 x 113.0 x 25.5

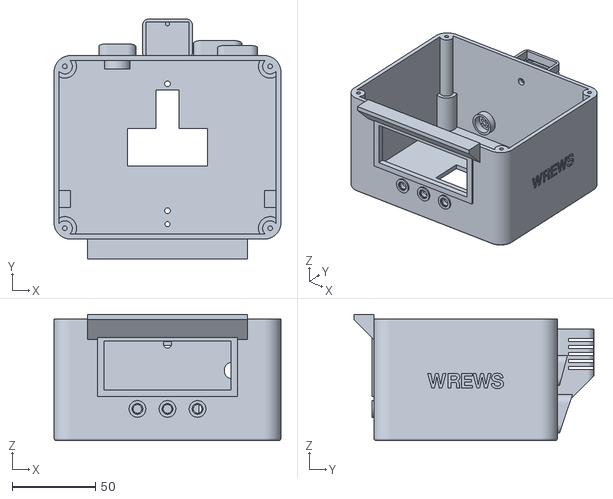
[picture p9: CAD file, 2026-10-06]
Carcasa_3D_/Carcasa_3D_v16/stl/4_caja.stl
136.0 x 144.0 x 75.7

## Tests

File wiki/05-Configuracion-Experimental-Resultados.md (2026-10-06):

[⬅ Volver al índice](00-Home.md)

# 5. Configuración experimental, resultados y análisis

## 5.1 Estrategia de validación

La validación de WREWS se desarrolló en **dos etapas complementarias**. Primero se utilizó **Wokwi** para comprobar la arquitectura, la adquisición de variables y la lógica de fusión en un entorno controlado. Posteriormente, el sistema fue ensamblado como un **prototipo físico funcional**, verificando el comportamiento real de los sensores, el procesamiento local en el ESP32 y la activación de las alertas.

### Etapa 1 — Simulación en Wokwi

El proyecto de simulación está disponible en:

<https://wokwi.com/projects/472250559337371649>

Se utilizaron *custom chips* para representar el BME280, el panel fotovoltaico y el INA219, además del sensor ultrasónico disponible en Wokwi.

Esta etapa permitió:

- modificar las variables de entrada de forma controlada;
- comprobar los cálculos intermedios;
- verificar la adquisición mediante I²C;
- probar la lógica de fusión;
- comprobar los estados NORMAL, PRECAUCIÓN y CRÍTICO;
- depurar el firmware antes de realizar el montaje físico.

### Etapa 2 — Prototipo físico

La implementación final integra:

- **ESP32** como unidad central de adquisición y procesamiento.
- **Sensor ultrasónico OKY3261/HC-SR04** para estimar el nivel.
- **BME280** para temperatura, humedad relativa y presión atmosférica.
- **Mini panel fotovoltaico + INA219** para obtener una estimación de la irradiancia solar.
- **LCD 16×2 I²C** para visualización local.
- **LED verde, amarillo y rojo** para representar los estados del sistema.
- **Buzzer** para la alarma sonora.

Para probar el nivel de manera controlada, la maqueta utiliza una **plataforma móvil que representa la superficie del agua**.

Al subir o bajar esta plataforma cambia la distancia detectada por el sensor ultrasónico y, por tanto, el porcentaje de nivel calculado.

Esto permite reproducir diferentes condiciones de almacenamiento sin exponer directamente la electrónica al agua.

Todo el procesamiento y la generación de alertas se realizan **localmente en el ESP32**, sin depender de una red de comunicaciones.

---

## 5.2 Procesamiento de la información

WREWS no determina el riesgo utilizando una sola variable.

El procesamiento integra tres componentes principales:

### 1. Disponibilidad actual

El sensor ultrasónico mide la distancia entre el sensor y la superficie que representa el agua.

A partir de la calibración del reservorio se transforma esta distancia en un **porcentaje de nivel**.

Un nivel elevado representa mayor disponibilidad de agua, mientras que un nivel bajo aumenta el riesgo de desabastecimiento.

### 2. Condiciones ambientales

El BME280 obtiene:

- temperatura;
- humedad relativa;
- presión atmosférica.

La temperatura y la humedad se utilizan para calcular el **déficit de presión de vapor (VPD)**.

El VPD se combina con la irradiancia estimada mediante el panel fotovoltaico y el INA219 para generar un **índice de condiciones favorables a la evaporación**.

Este índice no representa directamente la cantidad de agua evaporada. Su función es indicar qué tan favorables son las condiciones ambientales para que ocurra evaporación.

La presión atmosférica se conserva como una variable ambiental de contexto y no actúa directamente como disparador del riesgo.

### 3. Tendencia del nivel

El sistema compara varias mediciones del nivel a lo largo del tiempo.

Esto permite calcular una **tasa de descenso**, utilizada para identificar si el nivel está disminuyendo de manera acelerada.

Por tanto, WREWS puede diferenciar entre un nivel determinado que permanece relativamente estable y un nivel que está disminuyendo rápidamente.

---

## 5.3 Fusión del riesgo

El índice general de riesgo utiliza tres componentes:

```text
Déficit de nivel                 54 %   (50 % en el Challenge #1)
Condiciones evaporativas        30 %
Tasa de descenso                16 %   (20 % en el Challenge #1)
```

De forma conceptual:

```text
RIESGO =
0.54 × Déficit de nivel
+
0.30 × Índice evaporativo
+
0.16 × Tendencia
```

Los pesos del Challenge #2 son el vector del método AHP (Sección 3.2.5); las pruebas de simulación de la Sección 5.4 se hicieron con los pesos del Challenge #1.

Además del resultado ponderado, el firmware utiliza **reglas de seguridad**.

Estas reglas permiten escalar el estado cuando una variable individual alcanza una condición crítica, evitando que un riesgo importante quede oculto por el promedio de las demás variables.

Finalmente, WREWS clasifica la situación en:

- 🟢 **NORMAL**
- 🟡 **PRECAUCIÓN**
- 🔴 **CRÍTICO**

---

## 5.4 Resultados de simulación

Durante la etapa de diseño se definieron diferentes escenarios en Wokwi para comprobar las rutas de clasificación del algoritmo.

| Caso | Distancia | Temp. | Humedad | Irradiancia | Nivel | VPD | Índice evap. | Tasa descenso | Riesgo | Estado esperado |
|---|---|---|---|---|---|---|---|---|---|---|
| C1 — Escenario favorable | 4.0 cm | 18.0 °C | 70 % | 300 W/m² | 96.3 % | 0.62 kPa | 25.3 % | 0.0 pp/h | 9.4 % | 🟢 **NORMAL** |
| C2 — Riesgo combinado | 15.0 cm | 22.0 °C | 55 % | 600 W/m² | 55.6 % | 1.19 kPa | 49.8 % | 1.0 pp/h | 41.2 % | 🟡 **PRECAUCIÓN** |
| C3 — Nivel bajo | 20.0 cm | 24.0 °C | 45 % | 500 W/m² | 37.0 % | 1.64 kPa | 52.4 % | 1.5 pp/h | 53.2 % | 🟡 **PRECAUCIÓN** |
| C4 — Evaporación alta | 5.0 cm | 25.0 °C | 15 % | 650 W/m² | 92.6 % | 2.69 kPa | 77.4 % | 0.5 pp/h | 28.9 % | 🟡 **PRECAUCIÓN** |
| C5 — Nivel muy bajo | 27.0 cm | 20.0 °C | 60 % | 400 W/m² | 11.1 % | 0.94 kPa | 35.6 % | 0.5 pp/h | 57.1 % | 🔴 **CRÍTICO** |
| C6 — Evaporación extrema | 12.0 cm | 33.0 °C | 15 % | 1150 W/m² | 66.7 % | 4.28 kPa | 100.0 % | 1.0 pp/h | 50.7 % | 🔴 **CRÍTICO** |
| C7 — Tasa de descenso alta | 14.0 cm | 21.0 °C | 60 % | 350 W/m² | 59.3 % | 0.99 kPa | 34.1 % | 6.0 pp/h | 50.6 % | 🔴 **CRÍTICO** |
| C8 — Riesgo combinado ≥ 70 % | 24.0 cm | 29.0 °C | 25 % | 900 W/m² | 22.2 % | 3.00 kPa | 95.0 % | 3.0 pp/h | 79.4 % | 🔴 **CRÍTICO** |

En los ocho casos, el estado obtenido en la simulación coincidió con el estado esperado según el modelo.

> Estos valores corresponden a la etapa de simulación y fueron utilizados para validar la lógica del algoritmo. La implementación física utiliza la calibración correspondiente a las dimensiones reales de la maqueta.

> Las tasas de esta tabla se expresan en pp/h y corresponden a la formulación
> inicial de la tendencia (diferencia entre mediciones consecutivas), previa a
> la adopción de la regresión sobre ventana deslizante descrita en la Sección
> 3.2.4. Se conservan como evidencia del proceso de desarrollo.

> El caso C6 (33 °C, 15 % HR) constituye un escenario sintético fuera de la
> envolvente climática de la Sabana de Bogotá. Se incluyó para verificar la
> saturación del índice evaporativo, no como condición esperable en la región.

---

## 5.5 Resultados del prototipo físico

Una vez integrados los componentes se realizaron pruebas funcionales sobre el montaje completo.

El objetivo fue comprobar la cadena:

```text
SENSADO
   ↓
ADQUISICIÓN
   ↓
PROCESAMIENTO
   ↓
FUSIÓN DE INFORMACIÓN
   ↓
CLASIFICACIÓN
   ↓
ACTUACIÓN
```

Los resultados obtenidos fueron:

| Prueba | Elemento evaluado | Comportamiento esperado | Resultado |
|---|---|---|---|
| P1 | Sensor ultrasónico y nivel | La altura de la plataforma modifica coherentemente el nivel calculado | ✅ Correcto |
| P2 | BME280 | Lectura de temperatura, humedad y presión mediante I²C | ✅ Correcto |
| P3 | Panel fotovoltaico + INA219 | La señal cambia según la iluminación y permite estimar irradiancia | ✅ Correcto |
| P4 | Estado NORMAL | Condiciones favorables → LED verde y sin alarma crítica | ✅ Correcto |
| P5 | Estado PRECAUCIÓN | Condición intermedia → LED amarillo | ✅ Correcto |
| P6 | Estado CRÍTICO | Condición crítica → LED rojo y alarma sonora | ✅ Correcto |
| P7 | LCD 16×2 I²C | Visualización local de información y estado | ✅ Correcto |
| P8 | Procesamiento local | Clasificación y actuación sin conexión de red | ✅ Correcto |
| P9 | Tasa de descenso | Estimación de la pendiente por regresión sobre ventana deslizante, con banda muerta derivada del ruido medido | ✅ Correcto |

### 5.5.1 Caracterización del sensor y calibración de umbrales

Antes de fijar los parámetros de detección de tendencia se caracterizó experimentalmente el ruido del sensor ultrasónico. Con la plataforma inmóvil se tomaron 20 mediciones y se calculó su desviación estándar.

| Magnitud | Valor medido |
|---|---|
| σ de distancia | 0.4 cm |
| σ de nivel (sobre recorrido de 17 cm) | 2.4 pp |
| Ventana de estimación | 20 muestras · 20 s |
| Error típico de la pendiente | 1.8 pp/min |
| Banda muerta aplicada | 5.5 pp/min |

El error típico de una pendiente ajustada por mínimos cuadrados sobre *n* puntos repartidos en un lapso *T* es `SE = σ·√12 / (T·√n)`. La banda muerta se fijó en tres veces ese valor, lo que sitúa la probabilidad de falso positivo por debajo del 1 %. El procedimiento se ejecuta **automáticamente en cada arranque**, de modo que la banda se adapta al montaje concreto en lugar de depender de un valor elegido a priori.

Los umbrales de tendencia se calibraron mediante dos maniobras controladas de descenso continuo, registrando la pendiente máxima estimada en cada una:

| Maniobra | Pendiente máxima | Umbral derivado |
|---|---|---|
| Descenso lento sostenido | **46.9 pp/min** | PRECAUCIÓN = 33 pp/min (70 % de la lenta) |
| Descenso rápido | **98.2 pp/min** | CRÍTICO = 68 pp/min (media geométrica) |

Se eligió la media geométrica sobre la aritmética porque ambas maniobras se comparan por proporción —la rápida es 2.1 veces la lenta— y la geométrica deja el mismo margen relativo a cada lado: un factor de 1.45 en ambos casos.

El detector de discontinuidad impone además un techo: 8 pp entre mediciones consecutivas equivalen a 1.4 cm/s sobre este recorrido, por encima de lo cual el movimiento se clasifica como reposicionamiento y no como descenso.

**Cero del piranómetro.** Se caracterizó promediando 20 lecturas del INA219 con el panel sin iluminación, obteniendo −0.11 mA (−0.105 y −0.115 mA en dos arranques del 4 de octubre de 2026, equivalentes a ≈ 1 W/m²). Ese valor corresponde al offset del amplificador del INA219 más la corriente de fuga del panel, y se resta de todas las lecturas posteriores. Desde el firmware v7 solo se toma como cero si su magnitud es menor de 1 mA (10 W/m²): un valor mayor indica que había luz sobre el panel al encender, y tomarlo como cero restaría esa luz de todas las lecturas. La pendiente de la escala se deriva de la corriente de cortocircuito declarada por el fabricante (100 mA a 1000 W/m²), valor **pendiente de verificación experimental**: las etiquetas de paneles pequeños suelen declarar la corriente en el punto de máxima potencia, típicamente entre 5 y 10 % menor que la de cortocircuito.

Las pruebas permitieron comprobar el **funcionamiento completo del prototipo** y la correspondencia entre la lógica previamente validada en Wokwi y el comportamiento del montaje físico.

---

## 5.6 Análisis de resultados

### Validación progresiva

La simulación permitió depurar la lógica y comprobar el comportamiento esperado antes del montaje.

Posteriormente, la implementación física permitió confirmar que la arquitectura podía funcionar utilizando sensores y actuadores reales.

### Fusión de múltiples variables

El sistema no depende únicamente del porcentaje de nivel.

WREWS integra:

```text
Disponibilidad actual
        +
Condiciones ambientales
        +
Tendencia del nivel
        ↓
Riesgo hídrico
```

Esto permite obtener una evaluación más completa que la obtenida utilizando únicamente una medición instantánea del nivel.

### Respuesta de las alertas

Durante las pruebas físicas se verificaron los tres estados:

```text
NORMAL       → LED verde
PRECAUCIÓN   → LED amarillo
CRÍTICO      → LED rojo + buzzer
```

La pantalla LCD permite consultar localmente la información procesada por el sistema.

### Irradiancia estimada

El mini panel fotovoltaico y el INA219 proporcionan una señal relacionada con la radiación recibida.

En esta etapa del proyecto se utiliza como una **estimación experimental de irradiancia**.

Una medición metrológica precisa en W/m² requeriría una calibración frente a un instrumento de referencia.

### Presión atmosférica

Aunque el BME280 registra presión atmosférica, esta variable se utiliza principalmente como información de contexto.

Debido a que se espera una variación relativamente pequeña en un punto fijo de instalación, la presión no participa directamente en la lógica principal de generación de alertas.

### Alcance de la validación

La plataforma móvil permite reproducir cambios de nivel de manera controlada, repetible y segura.

Por tanto, las pruebas realizadas permiten validar el funcionamiento del prototipo a escala de laboratorio.

Una implementación en un reservorio real requeriría posteriormente calibración específica para su geometría y condiciones ambientales.

---

## 5.7 Validación del Challenge #2

El banco de pruebas del Challenge #2 se organizó según los bloques mínimos del enunciado. Las pruebas se hicieron sobre el equipo integrado (carcasa, tubo de PVC, alimentación por pilas) con el firmware v7, al sol, y con el tablero abierto desde celulares y PC conectados al hotspot que hace de WLAN de la zona.

> Las celdas marcadas con ⟨completar⟩ corresponden a mediciones que el equipo debe registrar con sus propios datos.

### Criterios de aceptación

Fijados en la hoja de trabajo del equipo antes de las pruebas:

| Prueba | Criterio de aceptación | Resultado |
|---|---|---|
| Nivel contra referencia | Error ≤ ±1 cm tras calibración | ⟨completar⟩ |
| Temperatura y humedad contra referencia | T ≤ ±1 °C; HR ≤ ±5 % | ⟨completar⟩ |
| Fusión y umbrales | ≥ 12 escenarios × 3 repeticiones; 0 falsos negativos en escenarios críticos; ≤ 1 falso positivo; sin oscilación al bajar de estado | ⟨completar⟩ |
| Latencia | Alarma física ≤ 2 s y tablero ≤ 5 s tras el evento (desde que se cumple la condición; la escalera de estados agrega la confirmación) | ⟨completar⟩ |
| Acceso restringido | Un dispositivo no autorizado no accede a los datos | ⟨completar⟩ |
| Caída de la WLAN | La alerta in situ continúa; reconexión automática < 60 s | ✅ alerta in situ continúa; tiempo de reconexión ⟨completar⟩ |
| Repetibilidad | Desviación estándar del nivel ≤ 0.5 cm; *jitter* del periodo de muestreo < 5 % con el tablero en uso | ⟨completar⟩ |
| Consumo | Consumo medio reportado; autonomía objetivo ≥ 24 h | ⟨completar⟩ |
| Larga duración | 12–24 h encendido sin reinicios | ⟨completar⟩ |

> Sobre el criterio de acceso: en la implementación final, un dispositivo fuera de la subred de la WLAN recibe **403**, y uno dentro de la WLAN pero sin sesión es enviado al inicio de sesión (**401** en la API). La lista blanca de IP planeada se reemplazó por la sesión con usuario y contraseña (ver [Sección 12.4](12-Mejoras-Challenge-1.md)).

### 5.7.1 Calibración contra referencia (*ground truth*)

| Sensor | Referencia | Procedimiento | Resultado |
|---|---|---|---|
| Nivel (HC-SR04 en el tubo) | Regla graduada junto al tubo | Distancias de lleno y vacío capturadas desde el tablero ("Usar como lleno/vacío"); luego 5 o más alturas de agua comparadas con el nivel del tablero | Lleno = ⟨completar⟩ cm, vacío = ⟨completar⟩ cm; error medio = ⟨completar⟩ pp; error máximo = ⟨completar⟩ pp |
| Panel + INA219 | ⟨completar: piranómetro o estación de referencia⟩ | Con sol, irradiancia de referencia en el tablero y "Calcular K" (regresión por el origen si hay varias medidas) | K = ⟨completar⟩ (W/m²)/mA (etiqueta: 10); R² = ⟨completar⟩ |
| Cero del panel (INA219) | Panel a oscuras | Promedio de 20 lecturas al arrancar | −0.105 y −0.115 mA (≈ 1 W/m²), restado de todas las lecturas |
| BME280 (T, HR) | Termohigrómetro digital (±1 °C, ±5 % HR según su ficha) | Sonda junto a las rejillas del BME280, 5 a 10 min de estabilización y una lectura por minuto durante 5 min | ΔT = ⟨completar⟩ °C; ΔHR = ⟨completar⟩ pp. Consistentes si caen dentro de la exactitud de la referencia |
| Buzzer (actuador) | Barrido de frecuencias, de 500 a 4000 Hz | Tono de 0.6 s por frecuencia, anotando cuáles suenan | Suena hasta **2000 Hz**; no suena desde 2500 Hz. El tono de crítico se ajustó de 2500 a 2000 Hz |

> El termohigrómetro tiene una exactitud del mismo orden que la del BME280 (±1 °C y ±3 % HR según su datasheet [15]), así que la comparación es una **verificación de consistencia** contra un instrumento independiente, no una calibración formal.

### 5.7.2 Verificación del modelo de evaporación

En cada arranque, el firmware ejecuta pruebas de Priestley-Taylor contra valores de referencia calculados de forma independiente (en Python, con las mismas ecuaciones). Resultados en el ESP32 real:

| Prueba | Esperado | Obtenido en el ESP32 | Resultado |
|---|---|---|---|
| Rs = 17 MJ/m², T = 14 °C (20/7), HR = 75 %, P = 75 kPa, Ra = 37.5 | Δ = 0.1038, γ = 0.0499, Δ/(Δ+γ) = 0.675, ea = 1.253, ET = 4.67 ± 0.05 mm/día | Δ = 0.1037, γ = 0.0499, f = 0.675, ea = 1.253, Rn = 13.46, ET = 4.675 | ✅ |
| Mismo caso con Ra = 36 | ET = 4.61 ± 0.05 | Rn = 13.27, ET = 4.608 | ✅ |
| Día despejado de referencia (Rs = Rso) | ET = ET_REF = 7.5 ± 0.05 | Rn = 20.80, ET = 7.483 | ✅ |
| Oscuridad (Rs = 0) | Rn = 0, ET = 0, sin valores negativos | Rn = 0, ET = 0 | ✅ |
| Ventana cubierta al 8 % | Sin estimación (CALCULANDO) | Sin estimación | ✅ |
| Modo campo: ventana de 120 s y de 24 h con la misma luz | Mismo Rs equivalente (43.2 MJ/m²) | 43.20 y 43.20 | ✅ |
| Modo demo: luz de mediodía despejado (G_pico = 1048.8 W/m²) y luz constante de 500 W/m² | Rs = Rso = 28.84 MJ/m²; con 500 W/m², Rs = 500/G_pico · Rso = 13.75 MJ/m² (± 0.1) | 28.84 y 13.75 MJ/m² (*) | ✅ (*) |

(*) Esta prueba se agregó en el firmware v7 y su salida no quedó registrada del monitor serial del ESP32. El valor reportado se obtuvo ejecutando en un PC la misma lógica del firmware (llenado de los 24 *buckets* con 120 muestras de 1 s y cálculo del modo demo) en precisión `float` de 32 bits, como la del ESP32: 28.8432 y 13.7510 MJ/m², frente a 28.8432 y 13.7510 esperados. Al arrancar, el equipo ejecuta esta misma prueba e imprime el resultado en el monitor serial.

Además se verificaron a mano lecturas reales del tablero (21.2 °C, HR 42.6 %, 75.1 kPa, sin luz): Δ/(Δ+γ) = 0.756 en el equipo frente a 0.754 calculado; ea = 1.08 kPa en ambos; índice evaporativo = 21.5 frente a 21.6; riesgo = 19.8 en ambos. Las diferencias son de redondeo.

### 5.7.3 Emulación acelerada de condiciones reales

| Condición emulada | Cómo | Observado |
|---|---|---|
| Descenso del nivel | Vaciado del tubo | Escalera NORMAL → PRECAUCIÓN → CRÍTICO en el LCD, los LEDs, el buzzer y el tablero, y vuelta a NORMAL al llenarlo |
| Sol fuerte y aire seco | Equipo al sol (irradiancia medida de 831 W/m², 27.5 °C, 24.8 % HR, VPD 2.76 kPa) | Con el modo demo inicial el índice se saturaba en 100 (ver abajo); tras la corrección queda en ≈ 90 (Priestley-Taylor 60 + VPD 30) |
| Calor sin luz | Secador sobre el BME280, panel a la sombra (44.7 °C, 16.1 % HR, VPD 6.65 kPa) | El índice se queda en 30: sin radiación, Priestley-Taylor da ET = 0 y solo aporta el componente de VPD, que ya está en su tope. Comportamiento esperado del método |
| Sombra o nube | Tapar el panel | El índice baja a medida que la ventana se llena con la luz nueva (hasta 120 s en modo demo) |

**Corrección encontrada en esta prueba.** En el modo demo inicial, la ventana de 120 s se extrapolaba a un día de 24 h con la misma luz. Con sol real, 831 W/m² equivalían a 72 MJ/m² "por día", 2.5 veces el máximo físico del sitio (28.8 MJ/m²), y la parte de Priestley-Taylor se saturaba siempre. Se cambió el modo demo para tratar la luz de la ventana como el mediodía de un día con esa nubosidad (índice de claridad, Sección 3.2.3). Con la regla nueva, un cielo parcialmente nublado (400 W/m², 21 °C, 50 % HR) pasa de un índice de ≈ 89 a ≈ 52, y el índice vuelve a distinguir días soleados de nublados.

### 5.7.4 Validación de la fusión y de los umbrales

| Caso | Condición | Estado esperado | Estado obtenido |
|---|---|---|---|
| F1 | Tubo lleno, sombra | NORMAL | ⟨completar⟩ |
| F2 | Tubo lleno, sol fuerte y seco (índice ≥ 85) | **PRECAUCIÓN** (la evaporación sola no lleva a crítico) | ⟨completar⟩ |
| F3 | Nivel ≈ 40 %, sombra | PRECAUCIÓN | ⟨completar⟩ |
| F4 | Nivel ≈ 40 %, sol fuerte | CRÍTICO por riesgo combinado (≥ 69.2) | ⟨completar⟩ |
| F5 | Nivel ≤ 15 % | CRÍTICO | ⟨completar⟩ |
| F6 | Descenso rápido sostenido (≥ 68 pp/min) | CRÍTICO por tasa | ⟨completar⟩ |
| F7 | Reposicionamiento brusco (> 8 pp en 1 s) | Sin alarma por tasa (discontinuidad) | ⟨completar⟩ |
| F8 | Sensor de nivel desconectado | FALLO | ⟨completar⟩ |
| F9 | Nivel justo en 50 % (borde de precaución) | PRECAUCIÓN (la regla es ≤ 50 %) | ⟨completar⟩ |
| F10 | Nivel justo en 15 % (borde de crítico) | CRÍTICO (la regla es ≤ 15 %) | ⟨completar⟩ |
| F11 | Recuperación: llenar el tubo desde CRÍTICO | CRÍTICO → PRECAUCIÓN → NORMAL, sin oscilar (3 ciclos de confirmación para bajar) | ⟨completar⟩ |
| F12 | Alarma silenciada desde el tablero y el estado empeora | El silencio se cancela y el buzzer vuelve a sonar | ⟨completar⟩ |

Falsos positivos observados: ⟨completar⟩. Falsos negativos observados: ⟨completar⟩.

> El caso F2 motivó una regla nueva: antes del cambio, el equipo quedaba en CRÍTICO al sol con el tubo lleno (nivel 94 %, riesgo 33). Era un falso positivo, y desde entonces la evaporación sola llega como máximo a PRECAUCIÓN (Sección 3.2.6).

### 5.7.5 Pruebas de la notificación

| Prueba | Criterio | Resultado |
|---|---|---|
| Latencia de la alerta | Tiempo entre el cambio físico y el aviso en el tablero. Esperado ≤ ~5 s: confirmación del estado (2 ciclos de 1 s) + consulta del tablero (cada 2 s) | ⟨completar con cronómetro o con la antigüedad del evento⟩ |
| Actualización del valor actual | El tablero muestra "dato de hace X s" | Valores observados de 0.1 a 0.4 s |
| Actualización del histórico | Las gráficas se actualizan cada 5 s con un punto cada 2 s | ✅ observado |
| Avisos | Cada cambio de estado muestra un aviso, suena y vibra | ✅ observado |
| Desactivación de la alarma desde el tablero | El buzzer se calla 15 min, los LEDs siguen, queda un evento | ✅ observado |
| Alarma física por estado | Tonos distintos en precaución (1000 Hz) y crítico (2000 Hz) | ✅ tras el ajuste a 2000 Hz |

### 5.7.6 Robustez y casos límite

| Prueba | Procedimiento | Resultado |
|---|---|---|
| Pérdida y reconexión de la WLAN | Apagar y volver a prender los datos o el hotspot con el tablero abierto | **Primera versión:** el tablero se quedaba en "Sin conexión" y, al recargar, la página no cargaba. **Tras la corrección** (cancelación de peticiones a los 4 s, reconexión sin cortar intentos en curso, Wi-Fi sin ahorro de energía y reinicio del servidor al volver la red), la alarma local siguió funcionando durante la caída y el tablero se recuperó solo al volver la red. En la prueba del tablero con red simulada, la recuperación tomó 1.2 s |
| Recarga y apertura desde otro dispositivo tras la caída | Recargar, abrir desde un segundo celular o PC | ✅ tras la corrección |
| Acceso con clave incorrecta | 5 intentos | ⟨completar⟩ (esperado: bloqueo de 30 s y evento por intento) |
| Acceso desde fuera de la WLAN | Celular con datos móviles | ⟨completar⟩ (esperado: no llega al equipo) |
| Valores fuera de rango | Distancia mayor que "vacío" o menor que "lleno" | El nivel se limita a 0 % o 100 % ⟨confirmar⟩ |
| Sensor de nivel o BME280 ausente | Desconectar | ⟨completar⟩ (esperado: FALLO con los tres LEDs) |
| Calibración inválida | Guardar "vacío" menor que "lleno" + 2 cm | El equipo la rechaza con el motivo en rojo y no cambia nada |
| Persistencia de la calibración | Apagar y encender | ⟨completar⟩ (esperado: "Cargados de la flash" en el arranque) |
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

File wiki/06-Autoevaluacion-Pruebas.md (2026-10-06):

[⬅ Volver al índice](00-Home.md)

# 6. Autoevaluación del protocolo de pruebas

Esta sección evalúa de forma crítica el protocolo de validación aplicado a WREWS, considerando tanto la etapa de simulación como la implementación física del prototipo.

---

## 6.1 Checklist de cobertura del protocolo

| Criterio | ¿Se cumple? | Evidencia / observación |
|---|---|---|
| Se prueban los tres estados de alerta: NORMAL, PRECAUCIÓN y CRÍTICO | ✅ Sí | Verificados en simulación y posteriormente sobre el prototipo físico |
| Se valida la lectura del nivel mediante sensor ultrasónico | ✅ Sí | La plataforma móvil permitió reproducir diferentes alturas y comprobar la variación del porcentaje de nivel |
| Se valida la adquisición de temperatura, humedad y presión | ✅ Sí | Lecturas obtenidas correctamente mediante el BME280 |
| Se valida el subsistema panel fotovoltaico + INA219 | ✅ Sí | La señal medida respondió a cambios de iluminación y fue utilizada para estimar irradiancia |
| Se valida el cálculo del VPD | ✅ Sí | Verificado durante las pruebas de simulación y procesamiento del firmware |
| Se valida el índice de condiciones favorables a la evaporación | ✅ Sí | Se comprobó la respuesta ante cambios en temperatura, humedad e irradiancia |
| Se valida la tasa de descenso | ✅ Sí | El firmware compara mediciones sucesivas del nivel para identificar descensos acelerados |
| Se valida la lógica de fusión de información | ✅ Sí | Se probaron escenarios de riesgo dependientes de nivel, evaporación, tendencia y riesgo combinado |
| Se valida la actuación visual mediante LEDs | ✅ Sí | Verde para NORMAL, amarillo para PRECAUCIÓN y rojo para CRÍTICO |
| Se valida la alarma sonora | ✅ Sí | El buzzer se activa correctamente en el estado CRÍTICO |
| Se valida la visualización local | ✅ Sí | La LCD 16×2 I²C presenta información del sistema y el estado correspondiente |
| Se valida el funcionamiento sin redes de comunicación | ✅ Sí | Toda la adquisición, procesamiento y actuación se realiza localmente en el ESP32 |
| Se prueba el prototipo físico completo | ✅ Sí | Se verificó la cadena completa desde los sensores hasta las alertas |
| Se prueban exactamente todos los valores en el borde de cada umbral | ⚠️ Parcial | Se probaron rangos representativos, pero no todos los valores límite exactos |
| Se realizan pruebas prolongadas de horas o días de operación continua | ❌ No | Fuera del alcance temporal de esta iteración |

### Pruebas añadidas en el Challenge #2

| Criterio del enunciado | ¿Se cumple? | Evidencia / observación |
|---|---|---|
| Calibración de sensores contra referencia, con error y factor de calibración | ⚠️ Parcial ⟨actualizar⟩ | Nivel contra regla y BME280 contra termohigrómetro (Sección 5.7.1); K del panel pendiente de calibrar con sol contra una referencia |
| Emulación acelerada de condiciones reales | ✅ Sí | Vaciado del tubo, sol y sombra sobre el panel, secador sobre el BME280 (Sección 5.7.3) |
| Validación de la fusión y los umbrales, con falsos positivos y negativos | ⚠️ ⟨actualizar⟩ | Casos F1–F12 (Sección 5.7.4). La prueba al sol con el tubo lleno detectó un falso positivo y motivó la regla de tope de la evaporación |
| Latencia de la alerta y actualización del valor actual y del histórico | ⚠️ ⟨actualizar⟩ | Actualización y avisos observados; falta el número de latencia medido |
| Desactivación de la alarma desde el tablero | ✅ Sí | El buzzer se calla 15 min, los LEDs siguen y queda el evento |
| Pérdida y reconexión de la WLAN | ✅ Sí | La alarma local siguió funcionando; el tablero se recuperó solo después de la corrección (Sección 5.7.6) |
| Acceso restringido a dispositivos autorizados | ⚠️ ⟨actualizar⟩ | Mecanismo implementado (misma subred + sesión); falta registrar la prueba con clave incorrecta y desde fuera de la WLAN |
| Valores fuera de rango y fallo de sensores | ⚠️ ⟨actualizar⟩ | Nivel limitado a 0–100 %; FALLO por sensor ausente ⟨registrar⟩ |
| Repetibilidad, precisión y consumo | ⚠️ ⟨actualizar⟩ | Ver Sección 5.7.7 |
| Verificación del modelo de evaporación contra valores de referencia | ✅ Sí | Autotest en el ESP32 real, con diferencias de redondeo frente al cálculo independiente (Sección 5.7.2) |

---

## 6.2 Fortalezas del protocolo

### Validación en dos etapas

El desarrollo utilizó primero un entorno de simulación y posteriormente hardware físico.

Esto permitió seguir una secuencia de validación progresiva:

```text
DISEÑO
   ↓
SIMULACIÓN
   ↓
DEPURACIÓN
   ↓
IMPLEMENTACIÓN FÍSICA
   ↓
CALIBRACIÓN
   ↓
VALIDACIÓN
```

La simulación permitió modificar las entradas de manera controlada y verificar la lógica de fusión antes de incorporar las posibles fuentes de error propias del hardware real.

### Cobertura funcional completa

Las pruebas no se limitaron a comprobar sensores de forma independiente.

También se verificó la cadena completa:

```text
SENSORES
   ↓
ADQUISICIÓN
   ↓
PROCESAMIENTO
   ↓
FUSIÓN
   ↓
CLASIFICACIÓN
   ↓
LCD + LEDs + BUZZER
```

Esto permitió confirmar que los módulos funcionan conjuntamente como un sistema y no solamente de manera aislada.

### Pruebas de los tres estados

Se comprobaron los estados:

- 🟢 NORMAL
- 🟡 PRECAUCIÓN
- 🔴 CRÍTICO

Esto permitió verificar tanto la lógica de clasificación como la respuesta física de los actuadores.

### Separación entre simulación y hardware

Los valores utilizados en Wokwi se mantuvieron identificados como parámetros de simulación, mientras que la implementación física se ajustó a las dimensiones y comportamiento real de la maqueta.

Esto evita interpretar los valores de la simulación como una calibración definitiva para un reservorio real.

---

## 6.3 Limitaciones identificadas

Aunque el prototipo cumplió los objetivos funcionales del reto, el protocolo presenta algunas limitaciones propias de la etapa de prototipado.

| Limitación | Implicación |
|---|---|
| La validación física se realizó sobre una maqueta | Los resultados confirman funcionamiento a escala de laboratorio, pero no sustituyen pruebas sobre un reservorio real |
| La superficie del agua se representó mediante una plataforma móvil | Permite una prueba repetible del sensor ultrasónico, pero no reproduce fenómenos como oleaje o reflexiones irregulares |
| La irradiancia se obtiene mediante un panel fotovoltaico e INA219 | La lectura funciona como estimación; una medición precisa en W/m² requeriría calibración con un instrumento de referencia |
| Los umbrales son parámetros iniciales de diseño | Deben ajustarse con datos reales de la región y del reservorio donde se instale el sistema |
| No se cubrieron todos los valores exactos de borde de los umbrales | Podrían realizarse pruebas adicionales específicamente sobre cada límite matemático |
| El extremo lleno del rango (3 cm) cae dentro de la zona ciega del sensor ultrasónico: por debajo de ~5 cm el transductor sigue resonando por su propio pulso cuando ya retorna el eco | Se observaron lecturas fallidas ocasionales con la plataforma en posición alta. Elevar el sensor por encima de 10 cm alargaría además el recorrido y reduciría el peso relativo del ruido |
| La escala temporal del banco de pruebas difiere en dos órdenes de magnitud de la de campo | Con el ruido y la geometría del montaje, la banda muerta supera ampliamente los umbrales que tendrían sentido en un reservorio real; ese régimen exigiría un transductor de presión sumergible o un sensor radar |
| No se caracterizó el consumo energético | El diseño contempla alimentación por panel y batería, pero no se midió el consumo por modo ni se dimensionó la autonomía; queda pendiente implementar *deep sleep* con despertar por alarma |
| **(Ch. #2)** El Wi-Fi opera sin ahorro de energía | Necesario para que el tablero responda siempre con hotspots de celular, pero aumenta el consumo y reduce la autonomía con pilas |
| **(Ch. #2)** El tablero va por HTTP, sin TLS | La clave viaja una vez al iniciar sesión y solo la protege el WPA2 de la WLAN; las sesiones se pierden si el equipo se reinicia |
| **(Ch. #2)** Las redes Wi-Fi van grabadas en el firmware (hasta dos) | Usar otra red exige reprogramar el equipo |
| **(Ch. #2)** El modo demo supone que la luz medida es la del mediodía de un día típico de 12 h | Sirve para pruebas cortas; el valor de campo sale de la ventana de 24 h, que tarda 12 h en estar disponible |
| **(Ch. #2)** El banco de pruebas no es un embalse | Valida la cadena de cálculo y la respuesta del índice evaporativo, no los mm/día absolutos; G ≈ 0 es un supuesto que no se cumple en agua profunda |
| **(Ch. #2)** Umbrales de evaporación 60 / 85 sin datos locales | Siguen siendo un supuesto; el método para cerrarlos (percentiles de una estación del IDEAM) queda como trabajo futuro |
| **(Ch. #2)** La referencia de humedad y temperatura es del mismo orden de exactitud que el BME280 | La comparación es una verificación de consistencia, no una calibración formal |
| **(Ch. #2)** La caja impresa corresponde a una versión anterior del diseño | ⟨completar: la tapa no ajusta y el USB-C no queda accesible; se reimprime para el tercer corte⟩ |

---

## 6.4 Evaluación del prototipo físico

La implementación física permitió validar aspectos que no podían comprobarse completamente en simulación.

Entre ellos:

- estabilidad de las lecturas del sensor ultrasónico;
- funcionamiento real del bus I²C;
- lectura del BME280;
- interacción entre panel fotovoltaico e INA219;
- visibilidad de la información en la LCD;
- actuación física de los LEDs;
- funcionamiento del buzzer;
- respuesta integrada del ESP32 ante cambios de nivel.

Uno de los aspectos más importantes fue comprobar que los estados calculados por el algoritmo producen una respuesta física coherente.

```text
NORMAL
→ LED verde
→ buzzer apagado

PRECAUCIÓN
→ LED amarillo
→ alerta visual

CRÍTICO
→ LED rojo
→ buzzer activo
```

---

## 6.5 Conclusión de la autoevaluación

El protocolo aplicado permitió validar satisfactoriamente el objetivo central de WREWS: **adquirir múltiples variables, procesarlas localmente, fusionar la información y generar alertas tempranas coherentes ante diferentes escenarios de riesgo hídrico**.

La combinación de simulación y prototipado físico fortaleció la validación, ya que permitió comprobar tanto la lógica matemática del sistema como su comportamiento real utilizando sensores y actuadores.

Las principales limitaciones restantes corresponden a una futura validación de campo, calibración metrológica y pruebas prolongadas, no al funcionamiento básico del prototipo presentado.

En el Challenge #2 el protocolo se amplió a los bloques que exige el enunciado (calibración, emulación acelerada, fusión, notificación, robustez y desempeño). Su valor principal estuvo en que **encontró fallas reales que se corrigieron**: la saturación del índice evaporativo con sol real en modo demo, el falso positivo de CRÍTICO por evaporación con el tubo lleno, el tablero que no se recuperaba tras una caída de la WLAN y el tono de crítico que el buzzer no podía reproducir.

---

[⬅ Anterior: Configuración experimental y resultados](05-Configuracion-Experimental-Resultados.md) · [⬆ Índice](00-Home.md) · [Siguiente: Conclusiones y trabajo futuro ➡](07-Conclusiones-Trabajo-Futuro.md)

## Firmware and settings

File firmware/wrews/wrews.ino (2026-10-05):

// ============================================================================
//  WREWS - Water Risk Early Warning System
//  Firmware del prototipo funcional  ·  v7
//  Challenge #2 - Internet de las Cosas - Universidad de La Sabana - 2026-2
//  v7: tablero de control web en la WLAN (servidor embebido, sesiones,
//      historial y eventos) y medicion en su propia tarea de FreeRTOS.
//  v6: el indice evaporativo pasa a ser evaporacion potencial diaria con
//      Priestley-Taylor (1972) y parametros FAO-56 (Allen et al., 1998).
// ----------------------------------------------------------------------------
//  Monitorea el nivel de un reservorio junto con las variables meteorologicas
//  que gobiernan la evaporacion, fusiona las tres senales en un indice de
//  riesgo hidrico y emite alerta LOCAL (LCD + LEDs + buzzer) que no depende
//  de la red. Ademas publica un tablero de control web dentro de la WLAN de
//  la zona (valor actual, historico, eventos y silencio de la alarma).
//
//  ARCHIVOS: wrews.ino (este), tablero.h (paginas web), secrets.h (red y
//  clave del tablero; no se sube, ver secrets.example.h).
//
//  PARAMETROS DEL BANCO DE PRUEBAS
//  Las constantes de tiempo y las escalas de tasa corresponden a la maqueta
//  de laboratorio, donde el nivel se mueve a mano en segundos. Los valores
//  equivalentes para un reservorio real y su justificacion estan en la wiki;
//  no se incluyen aqui porque no fueron validados experimentalmente.
//
//  REFERENCIAS
//  Los corchetes citan dos hojas complementarias del equipo:
//    [Ev n] "WREWS: referencias del modelo de evaporacion
//            (Priestley-Taylor + FAO-56)". Reemplaza las secciones 2 y 6 de
//            la hoja de pesos.
//    [Pe n] "WREWS: de donde salen las formulas, los pesos y los umbrales".
//            Vigente para todo lo demas.
//  Las mas usadas:
//    [Ev 1] Priestley y Taylor, Mon. Weather Rev., 1972.
//    [Ev 2] = [Pe 1] Allen et al., FAO-56, 1998.
//    [Ev 5] = [Pe 2] Rhiat et al., panel como piranometro, 2023.
//    [Pe 5] Saaty, AHP, 1990.   [Pe 7][Pe 8] Planes Especiales de Sequia.
//  "Supuesto" marca los valores sin fuente directa, declarados en la wiki.
//
//  Librerias: Adafruit BME280 / Adafruit Unified Sensor / Adafruit INA219 /
//             LiquidCrystal I2C (Frank de Brabander)
// ============================================================================

#include <Wire.h>
#include <Adafruit_Sensor.h>
#include <Adafruit_BME280.h>
#include <Adafruit_INA219.h>
#include <LiquidCrystal_I2C.h>
#include <WiFi.h>
#include <WiFiMulti.h>
#include <WebServer.h>
#include <ESPmDNS.h>
#include <Preferences.h>
#include <stdarg.h>
#include "tablero.h"

// Red y usuario del tablero. secrets.h NO se sube al repositorio: se crea
// copiando secrets.example.h y llenando los datos del hotspot.
#if __has_include("secrets.h")
#include "secrets.h"
#else
#error "Falta secrets.h: copie secrets.example.h como secrets.h junto a wrews.ino y complete la red y la clave"
#endif

// ===========================================================================
//  PINES Y POLARIDAD
// ===========================================================================
const uint8_t PIN_SDA      = 21;
const uint8_t PIN_SCL      = 22;
const uint8_t PIN_TRIG     = 5;
const uint8_t PIN_ECHO     = 18;
const uint8_t PIN_LED_V    = 25;
const uint8_t PIN_LED_A    = 26;
const uint8_t PIN_LED_R    = 27;
const uint8_t PIN_BUZZER   = 19;

#define LED_ON      LOW      // LEDs en anodo comun
#define LED_OFF     HIGH
const int BUZZER_HZ = 2000;  // buzzer PASIVO: necesita PWM, no continua
const uint8_t  BUZZER_RES   = 8;                       // bits del PWM
const uint32_t BUZZER_MEDIO = 1u << (BUZZER_RES - 1);  // 50 %: onda cuadrada

// ===========================================================================
//  CALIBRACION DEL RECIPIENTE
//  Por debajo de ~5 cm el HC-SR04 [Pe 17] es poco fiable: el transductor sigue
//  resonando por su propio pulso cuando ya vuelve el eco. D_LLENO = 3 cm
//  esta dentro de esa zona; queda documentado como limitacion conocida.
// ===========================================================================
const float D_LLENO_DEF = 3.0, D_VACIO_DEF = 20.0;   // maqueta del Challenge 1
float D_LLENO_CM = D_LLENO_DEF;     // editables desde el tablero (flash)
float D_VACIO_CM = D_VACIO_DEF;

// ===========================================================================
//  PIRANOMETRO  [Ev 5][Ev 6]
//  La corriente de cortocircuito de una celda es lineal con la irradiancia
//  [Ev 5]. El shunt de 0.1 ohm del INA219 [Ev 6] mantiene el panel
//  practicamente en corto, que es la condicion donde esa linealidad se cumple.
//  K_PANEL = 1000 W/m2 / I a pleno sol, con los 100 mA de la etiqueta.
//  TODO calibrar con sol (no con la lampara halogena, otro espectro) contra un
//  piranometro o estacion, regresion por el origen: la etiqueta suele dar Imp,
//  no Isc, y el K real quedaria cerca de 9-9.5 [Ev sec. 4].
// ===========================================================================
const float K_PANEL_DEF = 10.0;
float K_PANEL_WM2_POR_MA = K_PANEL_DEF;   // editable desde el tablero (flash)
float OFFSET_PANEL_MA  = 0.0;   // cero de oscuridad, medido al arrancar

// Una corriente de reposo mayor que esto no es error del INA219 sino luz
// sobre el panel al encender: tomarla como cero restaria esa luz de todas
// las lecturas. 1 mA = 10 W/m2, muy por encima del offset tipico del sensor.
const float OFFSET_MAX_MA = 1.0;

// ===========================================================================
//  EVAPORACION POTENCIAL: PRIESTLEY-TAYLOR + FAO-56  [Ev 1][Ev 2]
//  Supuestos (documentados tambien en la wiki):
//  - Superficie de agua libre sin efecto oasis [Ev 1]. El sitio objetivo es
//    un embalse; el banco de pruebas no cumple este supuesto y solo valida la
//    cadena de calculo, no el valor absoluto de evaporacion.
//  - G = 0 a escala diaria. Supuesto: [Ev 2] ec. 42 lo justifica para suelo;
//    en agua profunda [Ev 7][Ev 8] advierten lo contrario.
//  - Rnl con FAO-56 ec. 39 [Ev 2] (calibrada para tierra) sobre agua:
//    aproximacion habitual, declarada.
//  - Ra fijo para latitud ~4.9 N: error < 3 % en ET a lo largo del ano [Ev 2].
//  - En modo demo la luz de la ventana corta se toma como el mediodia de un
//    dia con esa nubosidad (indice de claridad G / G_pico, con G_pico de un
//    dia despejado de 12 h). Supone una forma de dia tipica; no reemplaza
//    la ventana de 24 h de campo. Supuesto.
//  - El VPD del indice es el de la ventana (es medio - ea), no el instantaneo.
//  - La evaporacion sola lleva como maximo a PRECAUCION (ver calcularObjetivo).
//  ET_REF, el modo y la ventana demo se editan desde el tablero (flash);
//  las demas son constantes del modelo y se cambian solo aqui.
// ===========================================================================
const float ALPHA_PT      = 1.26;      // [Ev 1] agua libre sin adveccion; [Ev 10] da 1.11 en tropico de altura
const float ALBEDO_AGUA   = 0.06;      // [Ev 4]; [Ev 8] midio 0.041 y 0.079
const float LAMBDA_MJ_KG  = 2.45;      // [Ev 2] calor latente a ~20 C
const float SIGMA_MJ      = 4.903e-9;  // [Ev 2] ec. 39, MJ K^-4 m^-2 dia^-1
const float ALTITUD_M     = 2560.0;    // [Ev 2] ec. 37, SOLO para Rso: gamma usa la P medida
const float RA_FIJO_MJ    = 36.0;      // [Ev 2] ec. 21 y anexo 2, MJ/m2 dia

// ET de un dia despejado del sitio (Rs = Rso, T 16 C [22/8], HR 65 %,
// P 75 kPa) con este mismo modelo [Ev 1][Ev 2]: 7.48 mm/dia. Asi el indice
// es la fraccion de la demanda evaporativa maxima posible [Ev sec. 6].
const float ET_REF_DEF = 7.5;
float ET_REF_MM_DIA = ET_REF_DEF;       // editable desde el tablero (flash)

// Escala diaria: ventana movil de 24 h [Ev 1][Ev 2]
const float    N_HORAS_SOL     = 12.0;   // duracion del dia cerca del ecuador, [Ev 2] ec. 34
const bool     MODO_DEMO_DEF   = true;
bool           MODO_DEMO       = MODO_DEMO_DEF;     // editable (flash)
const uint32_t VENTANA_CAMPO_S = 86400;  // 24 h
const uint32_t VENTANA_DEMO_DEF = 120;   // promedio de luz que se toma como mediodia. Supuesto
uint32_t       VENTANA_DEMO_S  = VENTANA_DEMO_DEF;  // editable (flash)
const uint8_t  NUM_BUCKETS     = 24;
const float    COBERTURA_MIN   = 0.5;    // TODO: fraccion minima de ventana. Supuesto

// Fusion del indice evaporativo (opcion 2 de [Ev sec. 7]). El peso del VPD
// es el reparto aerodinamico de Penman gamma/(D+gamma) [Ev 2] a 16 C y
// 75 kPa (0.30); [Ev 7] respalda que ese termino importa a escala de dias.
// El VPD se lee como senal de variacion diaria, no como evaporacion que se
// suma: ALPHA_PT ya incluye en promedio la parte aerodinamica.
const float W_PT        = 0.7;
const float W_VPD       = 0.3;
const float VPD_REF_KPA = 2.0;    // Supuesto: pico realista en la Sabana, es(24C)=2.98

// ===========================================================================
//  PESOS DEL INDICE DE RIESGO  [Pe 5][Pe 6]
//  Vector de pesos del AHP de Saaty [Pe 5] con la matriz de [Pe sec. 3]
//  (nivel 2x evaporacion, 3x tasa; evaporacion 2x tasa): CR = 0.008 < 0.10.
//  Mismo metodo que el indice compuesto de sequia de [Pe 6].
// ===========================================================================
const float W_NIVEL = 0.54;   // disponibilidad actual: la variable de estado
const float W_EVAP  = 0.30;   // forzante externo dominante en El Nino
const float W_TASA  = 0.16;   // tendencia: la senal mas ruidosa de las tres

// ===========================================================================
//  UMBRALES
//  Nivel: fases de los Planes Especiales de Sequia de Espana [Pe 7][Pe 8]
//  (prealerta 0.50, emergencia 0.15); caso Chingaza 2024 en 16.5 % [Pe 9].
//  Riesgo: derivado de los de nivel [Pe sec. 5], estilo CDI europeo [Pe 11]:
//    PREC = W_NIVEL*(100-50) + W_EVAP*20 + W_TASA*20 = 36.2
//    CRIT = W_NIVEL*(100-15) + W_EVAP*60 + W_TASA*33 = 69.2
//  Evaporacion: el 100 % tiene base fisica (ET_REF); 60 / 85 son Supuesto.
//    TODO cerrarlos con percentiles 80 / 95 de una estacion IDEAM, metodo
//    del US Drought Monitor [Pe 10].
//  Tasa: calibracion experimental. Dos maniobras controladas de descenso
//  continuo dieron 46.9 pp/min (lenta) y 98.2 pp/min (rapida).
//  PRECAUCION = 70% de la lenta;  CRITICO = media geometrica de ambas, que
//  reparte el margen relativo por igual entre las dos maniobras.
// ===========================================================================
const float U_CRIT_NIVEL  = 15.0,  U_PREC_NIVEL  = 50.0;   // %
const float U_CRIT_RIESGO = 69.2,  U_PREC_RIESGO = 36.2;   // 0-100
const float U_CRIT_EVAP   = 85.0,  U_PREC_EVAP   = 60.0;   // 0-100
const float U_CRIT_TASA_DEF = 68.0, U_PREC_TASA_DEF = 33.0;
float       U_CRIT_TASA   = U_CRIT_TASA_DEF,  U_PREC_TASA = U_PREC_TASA_DEF;   // pp/min, editables (flash)
const float TASA_REF      = 100.0;                          // pp/min

// ===========================================================================
//  TEMPORIZACION Y VENTANA
// ===========================================================================
const unsigned long T_MUESTREO_MS = 1000;
const unsigned long T_PAGINA_MS   = 2500;
const uint8_t VENTANA_N    = 20;   // 20 s de historia para la pendiente
const uint8_t MIN_MUESTRAS = 6;
// Confirmacion asimetrica: retardos de alarma de ANSI/ISA-18.2 [Pe 3]
const uint8_t CONF_SUBIR   = 2;    // ciclos para escalar de estado
const uint8_t CONF_BAJAR   = 3;    // ciclos para desescalar

// Cambio de nivel en una sola muestra que se interpreta como discontinuidad.
// 8 pp sobre este recorrido equivalen a 1.4 cm/s: por encima de eso el
// movimiento se clasifica como reposicionamiento, no como descenso.
const float SALTO_DEF = 8.0;
float SALTO_DISCONTINUIDAD_PP = SALTO_DEF;   // editable desde el tablero (flash)

// Banda muerta de la tasa [Pe 3][Pe 4]: se calcula sola al arrancar a partir del ruido
// medido. BANDA_MANUAL es el respaldo si la caracterizacion sale contaminada.
const bool  BANDA_AUTO   = true;
const float BANDA_MANUAL = 5.0;   // pp/min
float BANDA_MUERTA       = 5.0;

// ===========================================================================
//  OBJETOS Y ESTADO
// ===========================================================================
Adafruit_BME280    bme;
Adafruit_INA219    ina(0x40);
LiquidCrystal_I2C *lcd = NULL;

bool hay_lcd = false, hay_bme = false, hay_ina = false;
uint8_t addr_lcd = 0, addr_bme = 0, addr_ina = 0;

float distancia_cm = NAN, nivel_pct = NAN, nivel_anterior = NAN;
float temp_c = NAN, hum_pct = NAN, pres_hpa = NAN, vpd_kpa = NAN;
float corriente_ma = NAN, irradiancia = 0;
float idx_evap = 0, tasa_ppm = 0, riesgo = 0, tasa_max = 0;
float ruido_dist_cm = 0, ruido_nivel_pp = 0;
bool  ultra_ok = false;

uint8_t s_nivel = 0, s_evap = 0, s_tasa = 0, s_riesgo = 0;  // severidades 0/1/2

// ---- Ventana movil de la evaporacion ------------------------------------
// 24 h a 1 Hz serian 86 400 muestras: no caben junto al servidor web. Cada
// bucket resume VENTANA/NUM_BUCKETS segundos y el arreglo es circular.
struct Bucket {
  float energia_rs_mj;           // suma de Rs*dt / 1e6
  float suma_t, suma_hr, suma_p; // P en kPa
  float t_max, t_min;
  float duracion_s;              // tiempo efectivamente cubierto
  uint16_t n_muestras;
};

struct Ventana {
  uint32_t duracion_s;
  Bucket   b[NUM_BUCKETS];
  uint8_t  i;                    // bucket que se esta llenando
};

struct ResultadoPT {
  float rs_dia_mj, rn_mj, delta, gamma, frac_pt, ea_kpa, et_mm_dia;
  float vpd_kpa;                 // VPD de la ventana: es medio - ea, [Ev 2] ec. 12 y 19
};

const uint8_t EVAP_CALCULANDO = 0, EVAP_OK = 1;
const char *NOMBRE_EVAP[2] = { "CALCULANDO", "OK" };

Ventana     ventana_evap;
ResultadoPT pt = { 0, 0, 0, 0, 0, 0, 0, 0 };
uint8_t     estado_evap = EVAP_CALCULANDO;
float       cobertura_ventana = 0;
unsigned long t_evap_prev = 0;

float    buf_nivel[VENTANA_N];
uint32_t buf_t[VENTANA_N];
uint8_t  buf_n = 0, buf_i = 0;

const uint8_t EST_NORMAL = 0, EST_PRECAUCION = 1, EST_CRITICO = 2, EST_FALLO = 3;
const char *NOMBRE_EST[4] = { "NORMAL", "PRECAUCION", "CRITICO", "FALLO" };

uint8_t estado = EST_NORMAL, estado_silenciado = EST_NORMAL;
uint8_t conf_contador = 0;
bool    silenciado = false;
unsigned long t_silencio = 0;
const unsigned long SILENCIO_MS = 15UL * 60UL * 1000UL;

//                     LED per,  on, BUZ per,  on
const uint16_t PAT[4][4] = {
  { 1000, 1000,    0,   0 },   // NORMAL      verde fijo, silencio
  { 1000, 1000, 4000, 150 },   // PRECAUCION  amarillo fijo, toque grave
  {  400,  200, 1200, 250 },   // CRITICO     rojo parpadea, pitido insistente
  {  600,  300, 3000, 120 }    // FALLO       los tres juntos, tono muy grave
};
// El buzzer del prototipo armado no suena por encima de ~2000 Hz (barrido de
// 500 a 4000 Hz el 2026-10-04: suena hasta 2000, nada desde 2500). Critico
// queda en 2000 Hz, una octava sobre precaucion: se distinguen bien.
//                       NORMAL  PREC  CRIT  FALLO
const int BUZ_HZ[4]  = {      0, 1000, 2000,  600 };

unsigned long t_pagina = 0;
uint8_t pagina = 0;
const uint8_t N_PAGINAS = 7;
unsigned long t_ultima_muestra = 0;    // millis() de la ultima muestra

// ---- Historial reciente (tablero) --------------------------------------
// Un punto cada HIST_CADA muestras: 300 puntos x 2 s = 10 min de historia,
// suficiente para ver una maniobra completa del banco de pruebas.
struct PuntoHist {
  uint32_t t_s;
  float nivel, riesgo, evap, tasa, temp, hum, irr;
  uint8_t estado;
};
const uint16_t N_HIST    = 300;
const uint8_t  HIST_CADA = 2;
PuntoHist hist[N_HIST];
uint16_t  hist_n = 0, hist_i = 0;
uint8_t   hist_cont = 0;

// ---- Eventos (notificaciones del tablero) ------------------------------
// gravedad: 0 informacion, 1 precaucion, 2 critico / fallo
struct Evento {
  uint32_t id, t_ms;
  uint8_t  gravedad;
  char     texto[64];
};
const uint8_t N_EVENTOS = 24;
Evento   eventos[N_EVENTOS];
uint8_t  ev_i = 0;
uint32_t ev_sig = 1;                   // id del proximo evento (0 = ninguno)
void registrarEvento(uint8_t gravedad, const char *fmt, ...);

// ---- Red y tablero ------------------------------------------------------
// Modo estacion (STA): el equipo se une a la WLAN de la Alcaldia (en la
// demo, el hotspot de un celular) y sirve el tablero dentro de ella.
const char *NOMBRE_HOST = "wrews";     // http://wrews.local en PC
const unsigned long WIFI_ESPERA_MS     = 15000;  // espera inicial en setup
const unsigned long WIFI_REINTENTO_MS  = 30000;  // respaldo si no reconecta solo
const unsigned long WIFI_INTENTO_MS    = 10000;  // tiempo de cada intento de respaldo
WiFiMulti redes;                       // red 1 y, opcional, red 2 (secrets.h)
WebServer servidor(80);
bool      wifi_ok = false;             // solo se usan desde loop()
char      ip_txt[16] = "0.0.0.0";
unsigned long t_reintento_wifi = 0;
uint16_t  reconexiones_wifi = 0;
bool      mdns_ok = false;
bool      servidor_listo = false;

// ---- Parametros de calibracion ------------------------------------------
// Los que se ajustan con mediciones del sitio. Se editan desde el tablero y
// se guardan en la flash (Preferences / NVS), asi la carcasa queda cerrada.
// Los pesos y los umbrales de nivel, riesgo y evaporacion NO estan aqui:
// estan justificados con referencias y se cambian solo en el codigo.
struct Parametros {
  float    d_lleno, d_vacio;          // cm, sensor -> agua
  float    k_panel;                   // (W/m2)/mA
  float    u_prec_tasa, u_crit_tasa;  // pp/min
  float    salto;                     // pp
  float    et_ref;                    // mm/dia
  bool     modo_demo;
  uint32_t vent_demo;                 // s
};
Preferences prefs;
const char *NVS_ESPACIO = "wrews";

// Sesiones del tablero: token aleatorio en una cookie HttpOnly.
struct Sesion { char token[33]; unsigned long t_ms; bool activa; };
const uint8_t N_SESIONES = 4;
const unsigned long SESION_MS = 12UL * 3600UL * 1000UL;   // 12 h
Sesion sesiones[N_SESIONES];
uint8_t fallos_login = 0;
unsigned long t_bloqueo_login = 0;
const uint8_t MAX_FALLOS_LOGIN = 5;
const unsigned long BLOQUEO_LOGIN_MS = 30000;

// ---- Concurrencia -------------------------------------------------------
// Tres hilos (requisito del Challenge 2: medir fuera del hilo principal):
//   tareaMedicion  nucleo 0  sensores, modelo, estado, historial
//   tareaAlarmas   nucleo 1  LEDs y buzzer cada 10 ms
//   loop()         nucleo 1  servidor web, Wi-Fi y LCD
// Las alarmas van aparte del servidor a proposito: un cliente lento o una
// caida de la WLAN no pueden congelar la alarma fisica.
//   mtx_estado protege TODAS las variables de estado de arriba (menos las
//              de red y sesiones, que solo toca loop()).
//   mtx_i2c    protege el bus I2C (LCD, BME280 e INA219 lo comparten).
// Orden fijo para no bloquearse: nunca tomar mtx_i2c teniendo mtx_estado.
// Ninguna ISR: el I2C y la coma flotante no deben ir dentro de una ISR.
SemaphoreHandle_t mtx_estado = NULL, mtx_i2c = NULL;
TaskHandle_t      tarea_medicion = NULL, tarea_alarmas = NULL;
const uint32_t    PILA_MEDICION  = 8192;   // printf con floats usa varios kB
const uint32_t    PILA_ALARMAS   = 4096;
const UBaseType_t PRIO_MEDICION  = 2;      // por encima de loop() (1)
const UBaseType_t PRIO_ALARMAS   = 2;
const BaseType_t  NUCLEO_MEDICION = 0, NUCLEO_ALARMAS = 1;

void bloquear(SemaphoreHandle_t m) { xSemaphoreTake(m, portMAX_DELAY); }
void liberar(SemaphoreHandle_t m)  { xSemaphoreGive(m); }

// Agrega un evento al registro circular que lee el tablero y lo repite por
// el monitor serial. Se llama con mtx_estado tomado.
void registrarEvento(uint8_t gravedad, const char *fmt, ...) {
  Evento &e = eventos[ev_i];
  e.id = ev_sig++;
  e.t_ms = millis();
  e.gravedad = gravedad;
  va_list ap;
  va_start(ap, fmt);
  vsnprintf(e.texto, sizeof(e.texto), fmt, ap);
  va_end(ap);
  ev_i = (ev_i + 1) % N_EVENTOS;
  Serial.printf(">>> [%lu] %s\n", (unsigned long)e.id, e.texto);
}

// Un punto de historia cada HIST_CADA muestras. Se llama con mtx_estado tomado.
void guardarHistorial() {
  if (++hist_cont < HIST_CADA) return;
  hist_cont = 0;
  PuntoHist &h = hist[hist_i];
  h.t_s    = millis() / 1000;
  h.nivel  = nivel_pct;
  h.riesgo = riesgo;
  h.evap   = idx_evap;
  h.tasa   = tasa_ppm;
  h.temp   = temp_c;
  h.hum    = hum_pct;
  h.irr    = irradiancia;
  h.estado = estado;
  hist_i = (hist_i + 1) % N_HIST;
  if (hist_n < N_HIST) hist_n++;
}

// ===========================================================================
//  SENSORES
// ===========================================================================

// Mediana de 5. El HC-SR04 no falla con desviaciones pequenas alrededor del
// valor bueno: falla con lecturas absurdas (ecos falsos, pulsos perdidos).
// El promedio se contamina con ellas; la mediana las descarta.
float leerDistancia() {
  const uint8_t N = 5;
  float v[N];
  for (uint8_t i = 0; i < N; i++) {
    digitalWrite(PIN_TRIG, LOW);  delayMicroseconds(4);
    digitalWrite(PIN_TRIG, HIGH); delayMicroseconds(10);
    digitalWrite(PIN_TRIG, LOW);
    unsigned long us = pulseIn(PIN_ECHO, HIGH, 30000UL);
    v[i] = (us == 0) ? -1.0 : (us * 0.0343 / 2.0);
    delay(12);
  }
  for (uint8_t i = 1; i < N; i++) {
    float k = v[i]; int8_t j = i - 1;
    while (j >= 0 && v[j] > k) { v[j+1] = v[j]; j--; }
    v[j+1] = k;
  }
  return v[N/2];
}

float distanciaANivel(float d) {
  return constrain(100.0 * (D_VACIO_CM - d) / (D_VACIO_CM - D_LLENO_CM),
                   0.0, 100.0);
}
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
void loop() {
  servidor.handleClient();
  vigilarWiFi();

  unsigned long ahora = millis();
  if (ahora - t_pagina >= T_PAGINA_MS) {
    t_pagina = ahora;
    pagina = (pagina + 1) % N_PAGINAS;
    mostrarPagina(pagina);
  }
  delay(2);              // cede el nucleo a las demas tareas
}

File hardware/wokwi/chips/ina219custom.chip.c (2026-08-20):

#include "wokwi-api.h"
#include <stdio.h>
#include <stdlib.h>
#include <stdint.h>

#define INA219_ADDRESS 0x40

typedef struct {
  i2c_dev_t i2c;

  pin_t vin_plus;
  pin_t vin_minus;

  uint8_t selected_register;
  uint8_t read_index;

} chip_state_t;


// --------------------------------------------------
// Leer la señal que llega desde el panel solar
// --------------------------------------------------

static float get_panel_voltage(chip_state_t *chip) {

  float vplus = pin_adc_read(chip->vin_plus);
  float vminus = pin_adc_read(chip->vin_minus);

  float voltage = vplus - vminus;

  if (voltage < 0) {
    voltage = 0;
  }

  return voltage;
}


// --------------------------------------------------
// Convertir señal del panel a corriente simulada
//
// Nuestro modelo:
// 0 V -> 0 mA
// 5 V -> 100 mA
//
// Más adelante podremos cambiar 100 mA
// por la Isc REAL de la celda que compremos.
// --------------------------------------------------

static float get_current_ma(chip_state_t *chip) {

  float voltage = get_panel_voltage(chip);

  float current_ma =
      (voltage / 5.0f) * 120.0f;

  return current_ma;
}


// --------------------------------------------------
// I2C
// --------------------------------------------------

static bool on_i2c_connect(
  void *user_data,
  uint32_t address,
  bool read
) {

  chip_state_t *chip = (chip_state_t *)user_data;

  if (address == INA219_ADDRESS) {

    if (read) {
      chip->read_index = 0;
    }

    return true;
  }

  return false;
}


// --------------------------------------------------
// Lectura de registros
// --------------------------------------------------

static uint8_t on_i2c_read(void *user_data) {

  chip_state_t *chip =
      (chip_state_t *)user_data;

  float current_ma =
      get_current_ma(chip);

  /*
   * Guardaremos corriente × 100
   *
   * Ejemplo:
   *
   * 42.35 mA
   *
   * se convierte en:
   *
   * 4235
   */

  uint16_t current_raw =
      (uint16_t)(current_ma * 100.0f);

  uint8_t result = 0;

  switch (chip->selected_register) {

    // Registro custom de corriente
    case 0x04:

      if (chip->read_index == 0) {

        result =
            (current_raw >> 8) & 0xFF;

      } else {

        result =
            current_raw & 0xFF;
      }

      chip->read_index++;

      break;


    // Registro de identificación simple
    case 0xFF:

      if (chip->read_index == 0) {
        result = 0x21;
      } else {
        result = 0x90;
      }

      chip->read_index++;

      break;


    default:

      result = 0;

      break;
  }

  return result;
}


// --------------------------------------------------
// Escritura I2C
// --------------------------------------------------

static bool on_i2c_write(
  void *user_data,
  uint8_t data
) {

  chip_state_t *chip =
      (chip_state_t *)user_data;

  chip->selected_register = data;
  chip->read_index = 0;

  return true;
}


static void on_i2c_disconnect(
  void *user_data
) {
}


// --------------------------------------------------
// Inicialización
// --------------------------------------------------

void chip_init() {

  chip_state_t *chip =
      malloc(sizeof(chip_state_t));

  chip->selected_register = 0;
  chip->read_index = 0;

  chip->vin_plus =
      pin_init("VIN+", ANALOG);

  chip->vin_minus =
      pin_init("VIN-", ANALOG);


  const i2c_config_t i2c_config = {

    .address = INA219_ADDRESS,

    .scl =
        pin_init("SCL", INPUT_PULLUP),

    .sda =
        pin_init("SDA", INPUT_PULLUP),

    .connect =
        on_i2c_connect,

    .read =
        on_i2c_read,

    .write =
        on_i2c_write,

    .disconnect =
        on_i2c_disconnect,

    .user_data =
        chip,
  };


  chip->i2c =
      i2c_init(&i2c_config);


  printf(
    "INA219 Custom iniciado en 0x40\n"
  );
}

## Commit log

2026-10-04 Firmware v6: evaporacion con Priestley-Taylor + FAO-56
    Reemplaza el indice 50 % radiacion + 50 % VPD por la evaporacion potencial diaria (Priestley-Taylor con parametros FAO-56) sobre una ventana movil de 24 buckets, con modo demo de 120 s. Indice = 0.7 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
2026-10-04 Firmware v7: tablero de control web en la WLAN
    Medicion en una tarea de FreeRTOS (nucleo 0) y alarmas en otra (nucleo 1), con mutex para el estado y el bus I2C. Wi-Fi en modo estacion con reconexion, servidor web embebido con inicio de sesion (co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
2026-10-05 editar constantes desde el tablero de control y corrección del buzzer
    [wrews.ino]
2026-10-05 corrección tablero de controlW
2026-10-05 Eevsporación en modo demo para que no se sature si hay mucho sol, VPD usando la ventana y dos redes de conexion posible
